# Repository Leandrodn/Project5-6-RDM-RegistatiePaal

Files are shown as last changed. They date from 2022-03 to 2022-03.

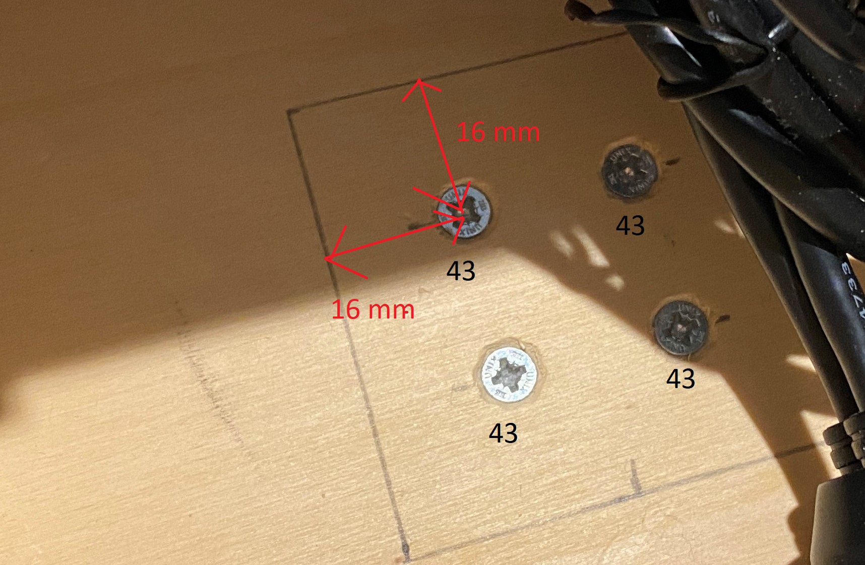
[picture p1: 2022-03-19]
How_To_Build_Your_Own_Registratiesysteem/Detail_Foto's/5291D550-8098-47D3-A0DD-A5EEF2B757EB.jpeg

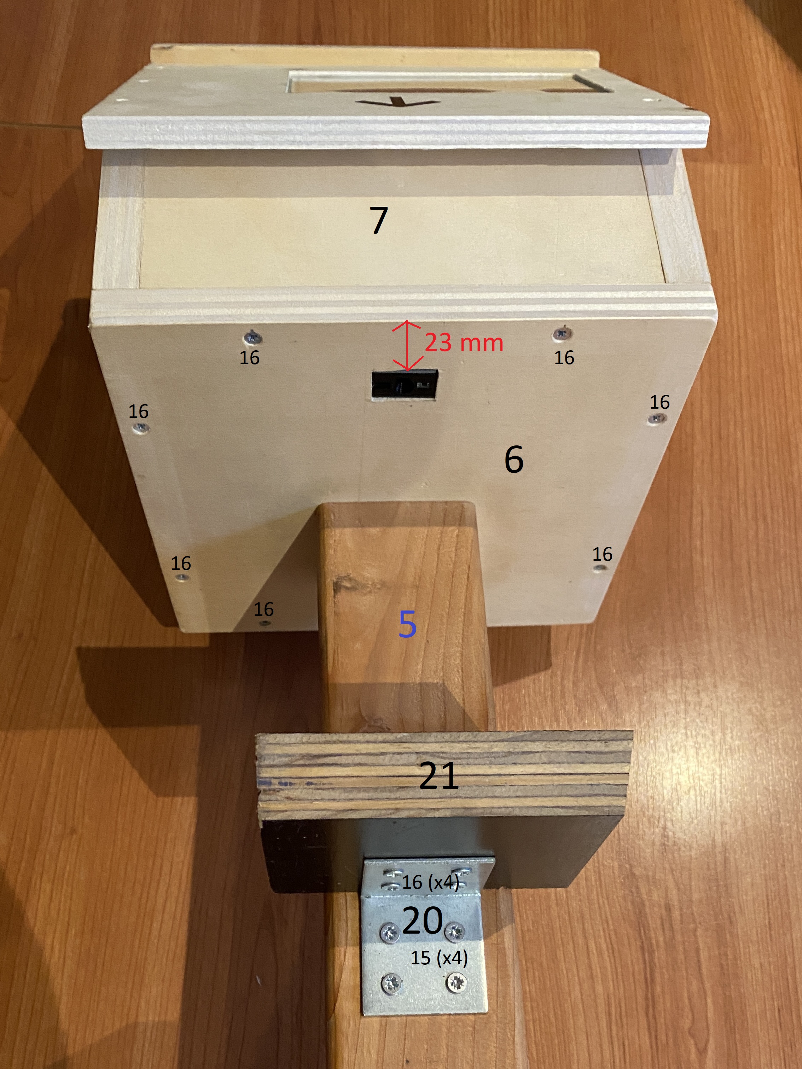
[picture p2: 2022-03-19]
How_To_Build_Your_Own_Registratiesysteem/Detail_Foto's/0E8D077D-FBBA-44C5-A444-DE62F57F8EC1.jpeg

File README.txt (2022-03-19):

Welkom bij de Opleverset van Project 56 - Help de RDM Werkplaatsen beter grip te krijgen op het gebruik van de werkplaatsen

In deze opleverset staan de volgende mappen met de volgende documenten:

- Aantekeningen
Hierin staan 2 tekst bestandjes met aantekeningen van de meeting met de FIT en opmerkingen van de instructeurs op het eerste prototype.

- Datasheets_en_Handleidingen
Hierin staan een aantal handleidingen van bijv. het scherm en scanner en "Pinout's" van de Raspberry Pi's.
	
- Eindmarkt
Hierin staat de powerpoint en bijbehorende video die is gebruikt tijdens de eindmarkt als marketing spotje.
Ook staat hierin de code die is gebruikt waarmee mensen hun studentnummer in konden voeren.
	
- How_To_Build_Your_Own_Registratiesysteem
Hierin staat het pdf document met complete uitleg hoe je het registratiesysteem kan nabouwen.
Ook staat er een mapje in met een aantal detailfoto's en belangrijke maten.
	
- Onderzoek
Hierin staan alle onderzoeken die uitgevoerd zijn voor dit project, zoals de hoofd en deelvragen in het hoofdonderzoek 
en bijv. de beste software voor het registratiesysteem.
Ook staan de belangrijkste onderzoeken erin, namelijk het experimenteel-, gebruikers- en literatuuronderzoek.

- Ontwerpen_en_Schema's
Hierin staan alle ontwerpen en schema's die horen bij dit project.
Onder andere het 3D-ontwerp staat erin met de afmetingen. Ook staan het elektrisch schema, flowchart, DFD, etc erin.

- Software
Hierin staat alle software die gemaakt is voor het registratiesysteem.
De python code van de registratiepaal, de database, de API en het Power BI bestand staan erin.

- Testrapport
Hierin staat het testrapport van alle relevante testen voor het registratiesysteem.

- Trello
Hierin staat een screenshot naar de Trello.
Ook staat er bij de overige documenten (in de 'root' van de opleverset) een tekst bestand met de link naar de trello.

- Userstories
Hierin staat het excel en pdf bestand van alle userstories die gemaakt zijn voor dit project.

- Reflectieverslagen
Hierin staan de reflectieverslagen van alle projectleden.

- Overige documenten
In de 'root' van de opleverset staan alle andere belangrijke en benodigde documenten zoals:
Het beveilgingsplan, de risicoanalyse, de projectdoel koppeling en de requirementsanalyse

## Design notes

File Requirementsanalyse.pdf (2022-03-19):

# Requirements Analyse – Project 56

Help de RDM-werkplaatsen om beter grip te krijgen op het gebruik van de werkplaatsen!

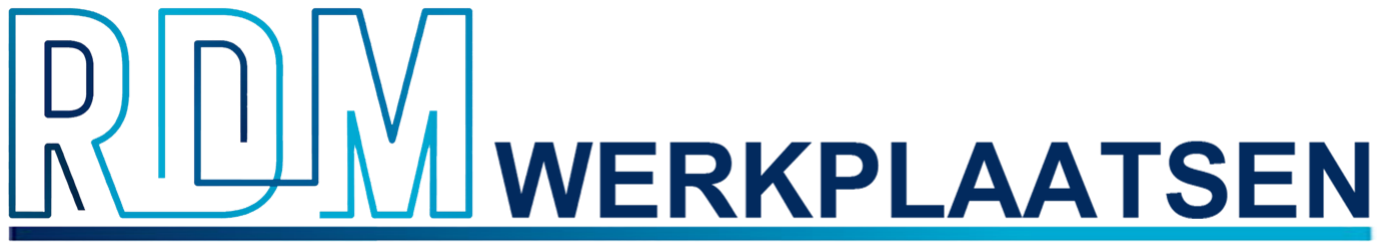
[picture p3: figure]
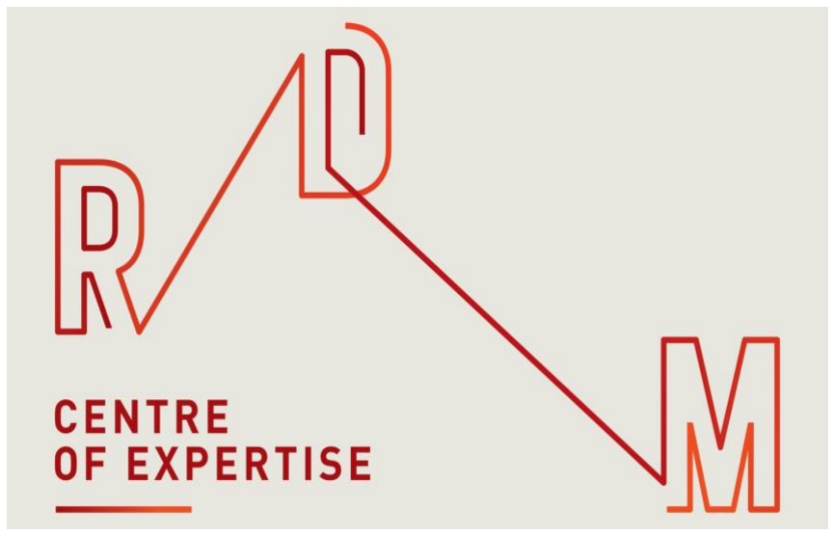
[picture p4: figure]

Projectleden:
- Matthijs Briel (0988991)
- Leandro de Nijs (1003440)
- Tom van Pelt (1003212)
- Gijs Kortlever (1003152)
Inleverdatum: 6 Februari 2022
Begeleiders: Erwin de Mos & S.M. Hekkelman Bedrijfsbegeleider (Product Owner): F.W.J. Joosten Gladon Gelegenheid: Eerste Kans

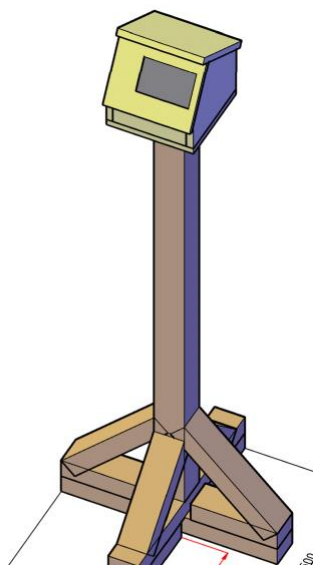
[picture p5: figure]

# Inhoudsopgave

# Inleiding

Deze analyse is geschreven voor Project 56: ‘Help de RDM-werkplaatsen om beter grip te krijgen op het gebruik van de werkplaatsen!’ van jaar 2 van TI. Bij dit project moet er een geautomatiseerd systeem ontworpen en (eventueel) gebouwd worden voor het registeren van bezoeken aan de werkplaatsen op de RDM door studenten. Nu gebeurt dat nog handmatig doordat ze ingetypt worden in Excel. Deze gegevens moeten opgeslagen worden en (makkelijk) uitgelezen kunnen worden voor nadere analyse.

Een ontwerp is bijvoorbeeld een systeem met kastjes bij de ingang van de werkplaatsen waar de student met zijn/haar HR-pas incheckt (en uitcheckt). Deze incheck wordt dan opgeslagen in een database die later weer uitgelezen kan worden.

## Ontwerpen

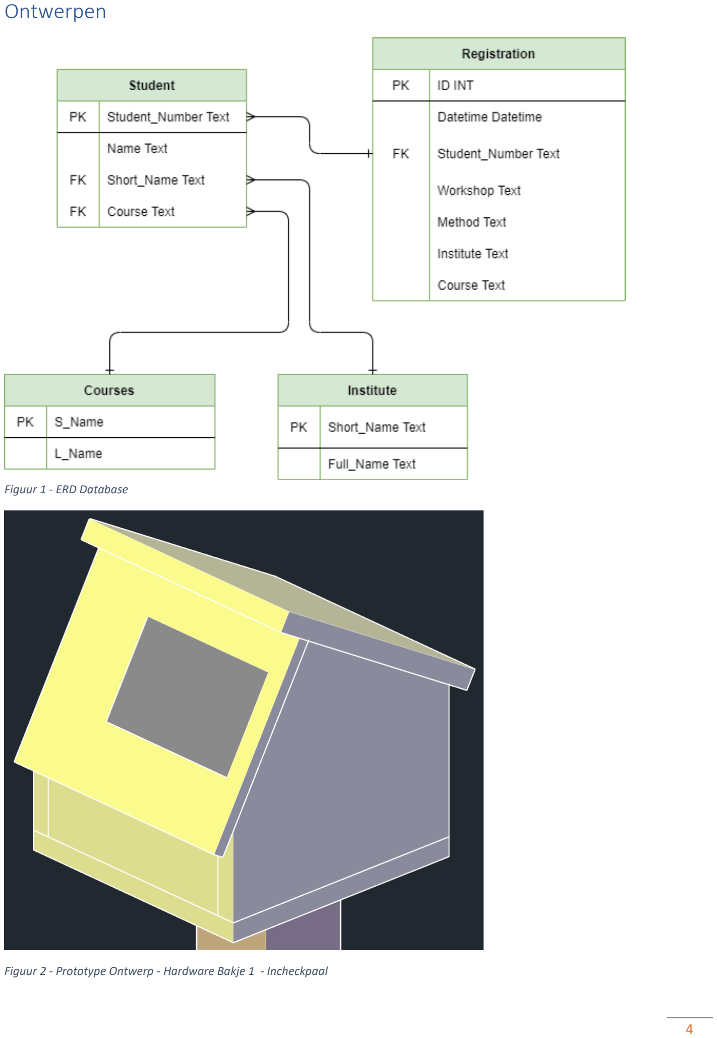
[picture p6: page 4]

Figuur 1 - ERD Database

Figuur 2 - Prototype Ontwerp - Hardware Bakje 1 - Incheckpaal

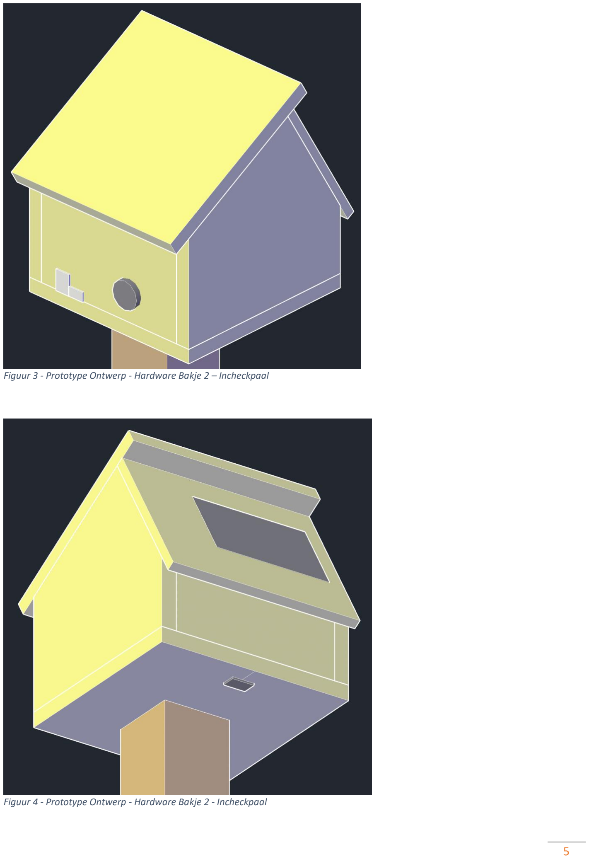
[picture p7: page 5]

Figuur 3 - Prototype Ontwerp - Hardware Bakje 2 – Incheckpaal

Figuur 4 - Prototype Ontwerp - Hardware Bakje 2 - Incheckpaal

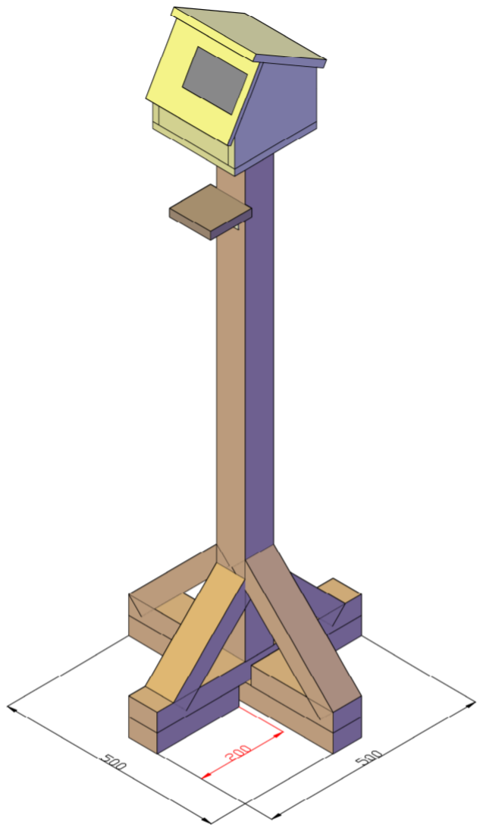
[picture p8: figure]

Figuur 5 - Prototype Ontwerp - Incheckpaal

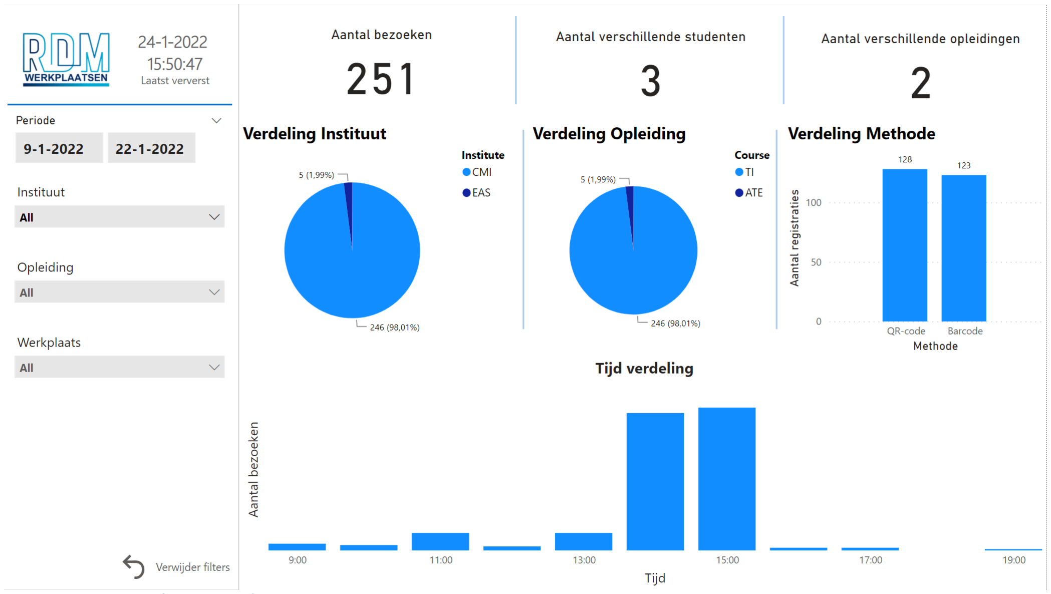
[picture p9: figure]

Figuur 6 – Power BI report – filters links – grafieken rechts

# Product Backlog: Allesbehalve Power BI

Nr. | Functionaliteiten | MoSCoW | Benodigdheden | Geschatte moeilijkheid (1-5)* | Acceptance Criteria
1 Barcode uitlezen met de Raspberry Pi en | 2D-scanner | M 2D barcode scanner | Raspberry Pi | 4 - Een schoolpas kan worden | uitgezelen met de 2D scanner
2 QR-code uitlezen met de Raspberry Pi | en 2D-scanner | M 2D barcode scanner | Raspberry Pi | 4 - Een QR-code kan worden | uitgezelen met de 2D scanner
3 Gegevens van een registratie worden | opgeslagen in een database. | M Database tabel met | student gegeven Database tabel met registraties API | 3 -Data van gescande pas | wordt uitgelezen, gecontroleerd en doorgestuurd.
4 Registraties kunnen worden opgevraagd | via een API | M Database | API | 4 -De registraties kunnen | worden opgehaald uit een database via de api.
5 | Beveiligingsplan | M | Concept-ontwerp om de beveiliging op te baseren. | 3 -Het plan houdt rekening met | zoveel mogelijk zwakheden.
6 | Privacy plan | M | Info over regels waaraan we ons moeten houden. | 3 -Het plan is in | overeenstemming met Nederlandse wetgeving.
7 | Risico log | M | Alle risico’s die zich tijdens en na het project kunnen voordoen | 2 -Alle risico’s zijn in kaart | gebracht met de impact die ze mogelijk hebben en hoe op te lossen.
8 Raspberry Pi maakt verbinding met het | internet | M Raspberry Pi maakt | verbinding met WiFi of Internetkabel | 2 -Raspberry Pi maakt | succesvol connectie met internet via wifi of kabel.

9 Er is duidelijk onderzoek gedaan om de | gemaakte keuzes te onderbouwen | M Onderzoeksverslagen / | Literatuuronderzoek / Gebruikersonderzoek / Experimenteel onderzoek | 3 -Onderzoek stelt duidelijke | vragen met antwoord en geeft adviserende conclusies.
10 Er zijn aanbevelingen gemaakt voor de | Hogeschool Rotterdam als zij zelf de paal willen implementeren | M Aanbevelingen | document | 3 -In het document staan de | aanbevelingen/aanpassingen die Hogeschool moet maken aan de registratiepaal
11 Op de registratiepaal wordt duidelijk | gemaakt dat de incheck is geslaagd op een scherm. | S Een scherm met GUI | Raspberry Pi | 4 -Op het scherm wordt met | een vinkje (of kruis) aangegeven of een scan is geslaagd of niet.
12 Op de registratiepaal wordt duidelijk | gemaakt dat de incheck is geslaagd met een buzzer. | S Een buzzer | Raspberry Pi | 2 -In de registratiepaal zit een | buzzer die een toon aangeeft of een registratie is geslaagd of niet.
13 Op het scherm worden de mogelijke | errors aangegeven. | S GUI | Scherm Raspberry Pi | 2 -Alle errors worden correct | opgevangen en weergegeven op het scherm van de registratiepaal.
14 En plankje om de hoogte voor registreren | aan te geven | W Registratiepaal | Plankje hout | 1 -Het plankje geeft de | correcte hoogte aan voor registreren.
15 Aan de registratiepaal zit een | stekkerdoos voor gemakkelijke toegang tot stroom en aansluiten op het stroomnet van de RDM | W Registratiepaal | Stekkerdoos | 1 -Stekkerdoos aan | registratiepaal is correct geïmplementeerd.

* 1 = zeer makkelijk / 5 = zeer moeilijk

# Product Backlog: Power Bi

Nr. | Functionaliteiten | MoSCoW | Benodigdheden | Geschatte moeilijkheid (1-5)* | Acceptance Criteria
1 | Data kan online worden weergegeven. | M | Power BI | 5 | -Data uit de database kan worden ingelezen via Power BI.
2 Power BI report is beveiligd achter een inlog scherm van | de Hogeschool. | M | Power BI | 1 | -In Power BI worden mensen toegevoegd die deel kunnen nemen aan het report. Inloggen gebeurt via HR-account
3 | Registraties worden uit de database gehaald via de API. | M | API, database, Power BI | 4 -registraties worden | opgehaald uit database via API
4 | Registraties kunnen worden gedownload naar Excel. | M | API, database, Power BI | 3 -de registratiedata | kan worden gedownload
5 De verdeling tussen de instituten wordt in een Pie chart | weergegeven | M API, database, | Power BI | 3 -Instituut data wordt | opgehaald en weergeven in een Pie chart.
6 De verdeling tussen de opleiding wordt in een Pie chart | weergegeven | M API, database, | Power BI | 3 -opleiding data | wordt opgehaald en weergeven in een Pie chart.

7 | Het aantal bezoeken wordt weergeven | M | API, database, Power BI | 3 -er wordt geteld | hoeveel bezoeken er zijn. Hier wordt ook aangeven het aantal studenten wat een werkplaats heeft bezocht.
8 | Er is in het report een globale filter van de werkplaatsen | M | Power BI | 2 | -er is een globale filter aan de linkerkant die filtert op werkplaats. Door de filter worden de grafieken veranderd
9 | Er is in het report een globale filter van de opleiding | M | Power BI | 2 | -er is een globale filter aan de linkerkant die filtert op opleiding. Door de filter worden de grafieken veranderd
10 | Er is in het report een globale filter van het instituut | M | Power BI | 2 | -er is een globale filter aan de linkerkant die filtert op instituut. Door de filter worden de grafieken veranderd

11 | Er is in het report een globale filter van de datum | M | Power BI | 2 | -er is een globale filter aan de linkerkant die filtert op datum. Hier kan een periode worden geselecteerd Door de filter worden de grafieken veranderd
12 | Registraties worden weergegeven in een tabel | S | API, database | 4 | -registratiedata wordt in een tabel weergegeven op de webapplicatie
13 | De data wordt minimaal een keer per dag ververst | S | Power BI | 1 | -het report is ingesteld dat het een keer per dag wordt ververst.
14 Er is een grafiek die het de QR-code / barcode | registraties bijhoud. | W API, database, | Power BI | 3 -de grafiek toont de | verdeling tussen QR-code en Barcode
15 Er is een grafiek die de tijdsverdeling van de | werkplaatsen bijhoudt. | W API, database, | Power BI | 3 -de grafiek toont de | tijdsverdeling aan. Hoe drukker hoe hoger de bar
16 Er wordt bijgehouden wanneer de data voor het laatst is | ververst. | W Power BI, custom | query | 3 -linksboven wordt | aangeven wanneer de data voor het laatst is ververst.

* 1 = zeer makkelijk / 5 = zeer moeilijk

# Specificatie

Nr. | Requirements | MoSCoW | Oorsprong | Acceptance Criteria | Test
1 Er kan een studentnummer van een QR-code | uit de HR-app worden uitgelezen met een QR-code scanner. | M | PO | Het studentnummer uit de QR-code uit de HR-app kan worden uitgelezen door deze code onder de QR-code scanner te houden. (zie 2 -backlog) | Als de QR-code uit de HR-app onder de QR-code scanner wordt gehouden, leest deze scanner hem uit en geeft de scanner een licht- en geluidssignaal dat de QR-code is uitgelezen.
2 Er kan een studentnummer van de barcode | op de HR-pas worden uitgelezen met een barcode scanner. | M | PO | De barcode wordt met succes uitgelezen van de HR-pas door de HR-pas voor de barcode scanner te houden. (zie 1 - backlog) | Als de barcode van de HR-pas onder de barcode scanner wordt gehouden, leest deze scanner hem uit en geeft de scanner een licht- en geluidssignaal dat de barcode is uitgelezen.
3 Er is een database in SQLite gemaakt waarin | de data staan die in de ERD staat, zie figuur 1. | M | Projectleden | De database is opgesteld volgens de ERD. (zie figuur 1) | Alle benodigde informatie die we nodig hebben, zit in de database.

4 Er is een RestAPI in python gemaakt die de | hardware met de database verbindt. | M Projectleden | / Expert | De API maakt correct verbinding voor het uitvoeren van POST/GET request. (zie 3 - backlog) | Code gemaakt die de data van de scanner naar de database kan sturen en ophalen. Ook zal de API worden ge-unit test zodat deze geen fouten bevat.
5 Er is een Power BI report gemaakt die data | ophaalt. | M Projectleden | / PO | De Power BI is gemaakt in overeenstemming met de PO. Deze haalt data op uit de database via de API. (zie 3 – backlog Power BI) | Power BI is voorgelegd aan de PO en voldoet aan haar wensen.
6 Power BI laat grafisch de registratie data uit | de database zien door middel van grafieken en diagrammen. | M | PO | In Power BI wordt de registratiedata correct uitgelezen en grafisch weergegeven. (zie 5/6/14/15 – backlog Power BI) | Power BI is voorgelegd aan de PO en voldoet aan haar wensen.

### 7 In Power BI kunnen ~4 mensen inloggen met

hun eigen inloggegevens.

M | PO | In Power BI zijn mensen toegevoegd die kunnen inloggen. Deze mensen kunnen ieder het report inzien door in te loggen met hun Hogeschool account. (zie 2 – backlog Power BI)
De toegevoegde
accounts kunnen
worden gebruikt om in
te loggen. Om dit te
testen zal de Power BI
worden geopend in een
incognito tabblad zodat
een persoon niet per
ongeluk al ingelogd
was.

### 8 De registratie data is te exporteren naar een

Excel bestand via Power BI.

M | PO | De tabel met alle registraties van de werkplaatsen is te downloaden naar een voor Excel compatibel bestand. (zie 4 – backlog Power BI)
Door op de knop te
drukken in Power BI zal
de data uit de database
worden geconverteerd
naar een bestand die
compatibel is met Excel
en vervolgens
gedownload naar de
computer waarop de
knop is ingedrukt.

### 9 Er is een ontwerp voor een incheckpaal met

een stevige voet van 50 x 50 cm, een paal met hoogte van ongeveer 110 cm en een ‘huisje’ bovenop de paal (volgens de afmetingen van 3D-ontwerpen) waarin een 2D code scanner, Raspberry Pi 3b (of hoger), 5 inch LCD scherm en kabels moeten passen. Ook moeten er uitsparingen zijn waarin de 2D code scanner past en uitsparingen voor het scherm aan de voorkant van het ‘huisje’. Daarnaast zitten er connectoren aan de achterkant zodat er stroom en eventueel een internetkabel kan worden aangesloten.

M | PO | Het ontwerp voldoet aan de gestelde eisen.
Het ontwerp bevat de
afmetingen die worden
gecontroleerd of die
binnen de waardes
vallen, ook zal de
hardware worden
geplaatst om te kijken of
er daadwerkelijk
voldoende ruimte is in
het bakje. De scanner
moet naar beneden
gericht staan en een
bar- en QR-code
kunnen scannen. Ook
moet de Raspberry Pi
aangesloten kunnen
worden als het bakje
dichtgeschroefd zit.

### 10 Er is duidelijk gemaakt via een scherm en/of

buzzer dat de bar- / QR-code goed is gescand en de registratie dus is geslaagd.

M PO /
Projectleden
/
Feedbackgr
oep

In het prototype wordt
duidelijk gemaakt dat een
registratie is geslaagd via de gestelde requirements. (zie 11/12 - backlog)

De methode voor het
duidelijk maken van een
geslaagde registratie
wordt getest door hier
code voor te schrijven
om een registratie te
simuleren. De barcode
op de HR-pas en de
QR-code in de HR-app
moet gescand kunnen
worden. Als een van de
codes gescand is moet
dit duidelijk gemaakt
worden door een
scherm, luide toon en/of
LED, zodat de gebruiker
weet of hij/zij goed
geregistreerd is.
11 Er is een architectuur ontwerp om duidelijk te | maken uit welke onderdelen het registratiesysteem bestaat. | M | PO | Alle losse onderdelen staan in het architectuur ontwerp en er wordt duidelijk met welk onderdeel deze is verbonden. | Architectuurontwerp is voorgelegd aan de feedback groep en is goedgekeurd.
12 Alle belangrijke risico’s zoals stroom uitval of | ziekte van een projectlid zijn in kaart gebracht in een risicolog. | M | Projectleden | Alle belangrijke risico’s zijn in kaart gebracht, de mogelijke gevolgen hiervan en hoe de risico’s voorkomen en/of verholpen kunnen worden. (zie 7 - backlog) | Risico’s zijn voorgelegd en besproken met PO. De PO keurt de risico’s goed of af.

13 In Power BI zijn globale filters die de data | filteren en weergeven | M | PO | De filters geven het verwachte resultaat in de grafieken. (zie 8/9/10/11 – backlog Power BI) | Filter op een aantal zaken en controller of dit is wat er wordt verwacht.
14 In de Power BI zijn de registraties zichtbaar | met bijbehorende data. | S Instructeurs | / PO | De verschillende registraties met datum zijn zichtbaar in een tabel in de webapplicatie. | Het resultaat wordt voorgelegd aan de PO.

# Changelog

Versie | Datum | Aanpassing | Auteur
1.0 | 15/10/2021 | Eerste versie | Matthijs Briel
1.1 | 15/10/2021 | Aanvulling | Matthijs Briel
1.2 | 17/11/2021 | Aanvulling Specificatie | Leandro de Nijs
1.3 | 17/11/2021 | Aanvulling backlog | Leandro de Nijs
1.4 | 20/11/2021 | Kleine lay-out aanpassing | Tom van Pelt
1.5 | 21/11/2021 | Ontwerpen toegevoegd / aanvulling specificatie | Tom van Pelt
1.6 | 21/11/2021 | Aanvulling | Leandro de Nijs
1.7 | 15/01/2022 | Wijziging van ontwerp foto’s registratie paal en afbeeldingen op Voorblad toegevoegd | Tom van Pelt
1.8 | 24/01/2022 | Grote aanpassing | Leandro de Nijs & Gijs Kortlever
1.9 | 31/01/2022 | Aangepaste ERD toegevoegd | Tom van Pelt

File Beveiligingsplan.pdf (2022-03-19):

# Beveiligingsplan – Project 56

Help de RDM-werkplaatsen om beter grip te krijgen op het gebruik van de werkplaatsen!


Projectleden:
- Matthijs Briel (0988991)
- Leandro de Nijs (1003440)
- Tom van Pelt (1003212)
- Gijs Kortlever (1003152)
Inleverdatum: 6 Februari 2022
Begeleiders: Erwin de Mos & S.M. Hekkelman Bedrijfsbegeleider (Product Owner): F.W.J. Joosten Gladon Gelegenheid: Eerste Kans


## Inhoudsopgave

## Hoofdstuk 1

### Data Flow Diagram (DFD)

- Zie Bijlage 1.

### Risicoanalyse algemeen / project specifiek

- In deze risicoanalyse wordt omschreven welke aanvallen (risico’s) er mogelijk zijn en hoe deze uitgevoerd kunnen worden.

Algemeen
Nr. | Risico | Impact (1-5)* | Kans (1-5)* | Hoe te voorkomen en hoe op te lossen.
1 | Componenten gaan kapot. | 4 | 2 | Kijken of er nog componenten zijn ter vervanging. Zo niet, dan de componenten bestellen. Komen de componenten niet binnen de huidige sprint aan, dan moet het door worden geschoven naar volgende sprint.
2 Componenten die besteld zijn komen | niet op tijd aan. | 3 | 2 | Kijken of de sprint nog voltooid kan worden. Zo niet, dan moet het door worden geschoven naar volgende sprint planning.
3 | Geen internetverbinding. | 5 | 3 | Er altijd rekening mee houden en dus belangrijke documenten downloaden in plaats van online te bekijken.
4 Tijdens een sprint erachter komen dat | wat er in de sprint backlog staat voor de huidige sprint, niet haalbaar is in de tijd (die nog over is). | 5 | 2 | Kijken welke user story aangepast / eruit gehaald moet worden om de sprint wel haalbaar te maken.
5 | Een projectlid wordt ziek. | 3 | 2 | Kijken wanneer het projectlid ziek is geworden. In het begin en kort ziek? -> dan is zijn deel nog haalbaar om te halen. In het midden/eind en langer ziek? -> Taakdeel verdelen over de andere projectleden.
6 Scholen gaan weer dicht i.v.m. nieuwe | coronamaatregelen. | 5 | 1 | Kijken wat er thuis gedaan kan worden en kijken of er bij iemand (veilig) afgesproken kan worden om aan het project te werken.
7 | Een projectlid stopt met de opleiding. | 5 | 1 | Taken van huidige sprint van stoppende projectlid verdelen over de rest van de projectleden. De andere projectleden moeten rekening houden met meer werk voor de rest van het project.

Project specifiek
Nr. | Risico | Impact (1-5)* | Kans (1-5)* | Hoe te voorkomen en hoe op te lossen.
1 | Opdrachtgever is niet bereikbaar. | 2 | 4 | Vooraf informeren wanneer de opdrachtgever bereikbaar is en dus optimaal gebruik maken van de contact-momenten.
2 | Budget raakt op. | 5 | 2 | Voorzichtig omgaan met de aankoop van componenten. En goed bijhouden wat en voor welke prijs we spullen hebben gekocht.
3 | Stroom valt uit op de RDM | 5 | 1 | Hier kunnen wij niet zo veel aan doen, dit moet worden opgelost door de werknemers bij de RDM. Wel kunnen we een tijdelijke oplossing bedenken.
4 | Internet valt weg op de RDM | 4 | 3 | Hier kunnen wij niet zo veel aan doen, dit moet worden opgelost door de werknemers bij de RDM. Wel kunnen we een tijdelijke oplossing bedenken.

* 1-5 = 1 is minst belangrijk, 5 is meest belangrijk

Legenda:
- Impact 1 = erg klein, heel erg makkelijk op te vangen als dit voorkomt
- Impact 5 = erg groot, moeten grote maatregelen worden genomen om dit probleem op te lossen
- Kans 1 = erg klein, komt eigenlijk niet voor, maar zou in theorie voor kunnen komen
- Kans 5 = erg groot, zeer aannemelijk dat dit voor kan komen tijdens een van de sprints

### Attack Tree

- Zie Bijlage 2

## Hoofdstuk 2

### Beveiligingsrisico’s

In onderstaande tabel staan de meest belangrijke en voorkomende beveiligingsrisico’s.

Risico Nr. | Risico | Uitvoering Risico
1 | Met requests naar de server is er toegang mogelijk naar de database. | Door URL’s die niet gebruikt worden door de API te gebruiken kunnen er requests naar de serve gestuurd worden die niet gecheckt worden door de API.
2 | Iemand kan bij de data in de database komen zonder de API te gebruiken. | Als er toegang is tot de bestanden hiërarchie van de server zou het bestand van database geopend kunnen worden.
3 | Iemand kan zomaar de registratiepaal openmaken en bij de binnenkant komen. | Iemand kan bij de binnenkant komen door een plankje weg te trekken doordat deze niet goed vastzit. Ook kan er bijvoorbeeld nog een gat zitten in de behuizing waardoor er zeer gemakkelijk bij gekomen kan worden.
4 | Iemand kan computer van de registratiepaal bedienen. | Iemand sluit een toetsenbord of muis aan via een usb-poort aan de binnenkant of buitenkant van de behuizing en kan zo de computer van de paal besturen en bijv. de registratie software (GUI) uitzetten of malware laten draaien.
5 | Iemand kan een bar/QR-code scannen die malware bevat | Iemand scant een QR-code met bijv. een commando waarmee er data kan worden gestuurd naar de database die de database kan hacken.
6 | Als iemand de juiste URL heeft van de API, kan deze zonder authenticatie de data inzien/versturen. | De URL is bekend bij iemand die hier eigenlijk niet tot geautoriseerd hoort te zijn. Deze persoon kan via deze URL de JSON-data uit de API ophalen en zelf weergeven.

### Maatregelen

In onderstaande tabel staan de maatregelen die genomen moeten worden om de beveiligingsrisico’s zoveel mogelijk te verhelpen.

Risico Nr. | Maatregel Nr. | Maatregel
1 | 1 | Specifieke URL’s in de database die over bepaalde delen van de database gaan. Alle requests naar de server die niet gelijk zijn aan een van deze URL’s worden genegeerd. Alleen POST en GET requests worden geaccepteerd. Vervolgens moet de URL ook kloppen met wat vastgelegd staat in de documentatie.
2 | 2 | In de API wordt alleen data die gelijk is aan afgesproken formats herkend, alles dat niet volgens de documentatie correct is wordt genegeerd en weggegooid. Denk hierbij aan extra ongewenste data toevoegen achter een legitiem data format. Deze data worden genegeerd doordat alleen de data met het juiste voorvoegsel wordt gepakt en deze data ook nog wordt gecheckt of het bijvoorbeeld de juiste string lengte of zelfs juiste inhoud bevat. Dit alles om te zorgen zodat alleen gewenste data überhaupt dicht bij de database kan komen.
3 | 3 | Het materiaal waarmee de registratiepaal wordt gemaakt is stevig en zit goed vastgeschroefd zodat er tenminste gereedschap aan toe moet komen om de registratiepaal open te maken. Eventueel kan het hout en de schroeven ook nog verlijmd worden zodat de registratiepaal niet meer uit elkaar te halen is. Als er gelijmd wordt is het aan te raden, om ergens een klepje te maken met een goed scharnier en slot erop zodat er toch nog bij de binnenkant gekomen kan worden, maar alleen door degenen die daartoe bevoegd zijn.
4 | 4 | Er moeten geen USB-poorten zijn gemaakt aan de buitenkant zodat er bijvoorbeeld geen toetsenbord of muis kan worden aangesloten. Voor het prototype wat er bij dit project wordt opgeleverd is dit wel zo, omdat het heel handig is met testen. Ook moet de touchscreen uitstaan op het scherm. Dit is makkelijk door gewoon geen software te installeren op de Pi die ervoor zorgt dat de touchscreen werkt. Default werkt de touchscreen al niet namelijk.
5 | 5 | In de software (GUI) van de registratiepaal moet worden gecheckt met bijvoorbeeld een if statement of de data die gescand wordt 7 tekens lang is en alleen uit cijfers bestaat. Dat is namelijk het format van een studentnummer. Daardoor kan er geen andere data dan alleen een studentnummer worden gestuurd naar de API.
6 | 6 | Zelf geen maatregelen voor genomen, wel een aanbeveling.

## Bijlagen

### Bijlage 1 – Data Flow Diagram

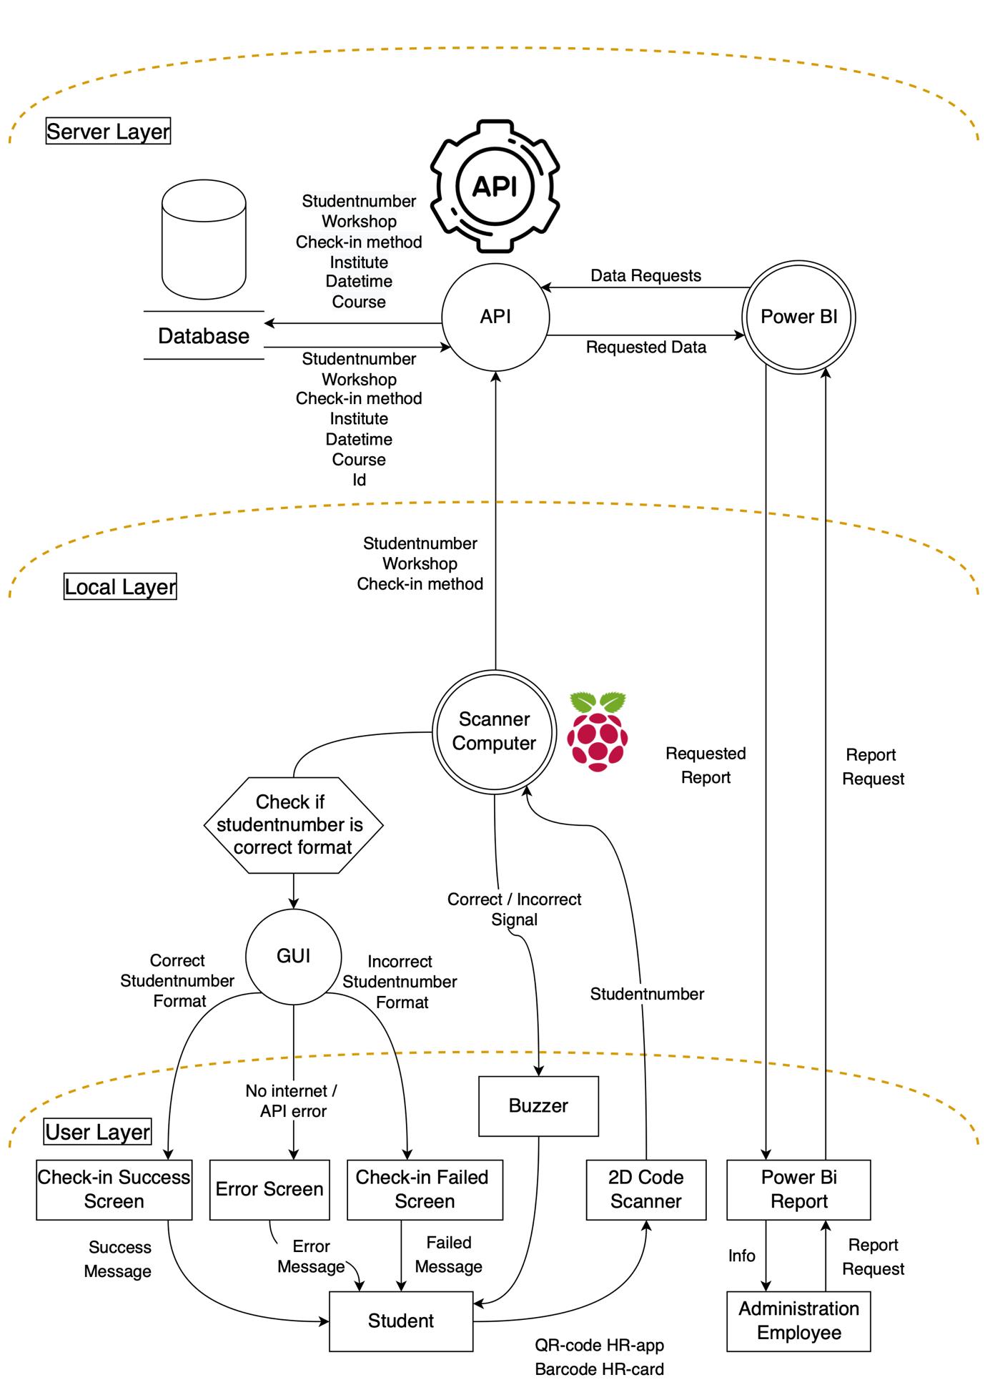
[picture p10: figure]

### Bijlage 2- Attack Tree

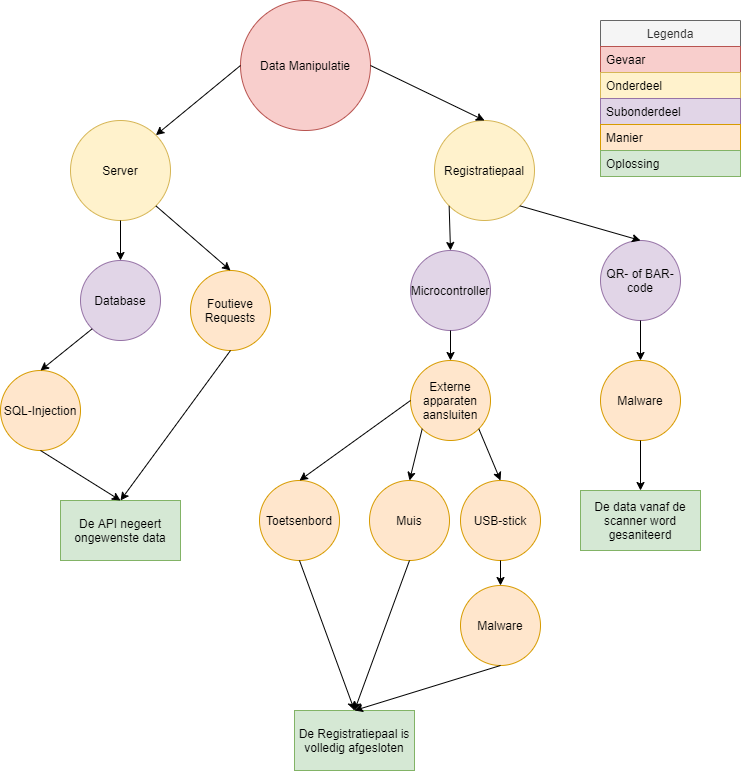
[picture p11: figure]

## Changelog

Versie Datum | Aanpassing | Auteur
1.0 | 15/12/2021 | Eerste versie | Matthijs Briel
1.1 | 19/12/2021 | Bijlage toegevoegd en kleine lay-out aanpassing | Tom van Pelt
1.2 | 15/01/2022 | Afbeeldingen op Voorblad toegevoegd | Tom van Pelt
1.3 | 24/01/2022 | Grote aanpassingen | Gijs Kortlever
1.4 | 26/01/2022 | DFD aangepast naar nieuwe versie | Tom van Pelt
1.5 | 30/01/2022 | Aanpassingen en grote aanvullingen | Tom van Pelt
1.6 | 31/01/2022 | Aanvulling / aanpassingen | Leandro de Nijs & Tom van Pelt & Gijs Kortlever

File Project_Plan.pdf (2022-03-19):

# Project Plan – Project 56

Help de RDM-werkplaatsen om beter grip te krijgen op het gebruik van de werkplaatsen!

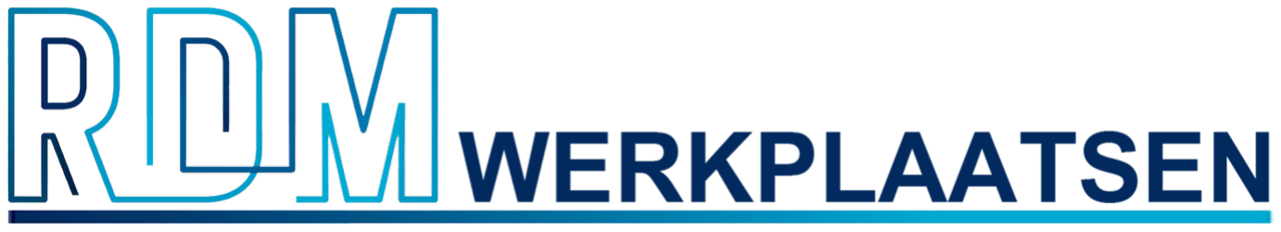
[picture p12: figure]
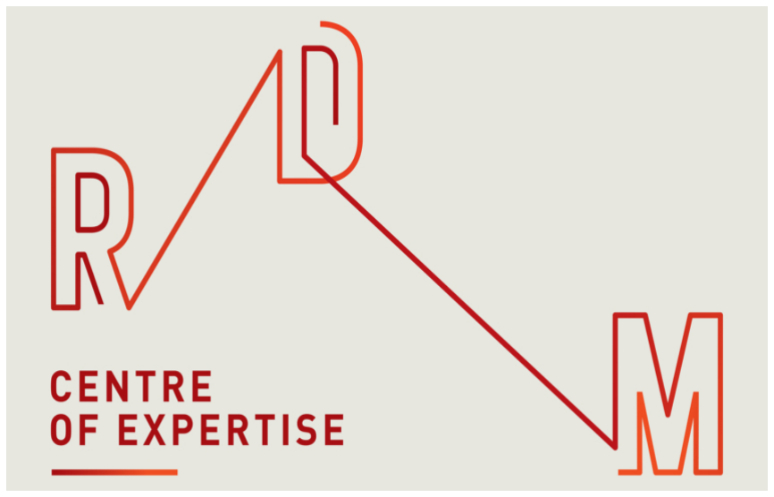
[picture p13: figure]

Projectleden:
- Matthijs Briel (0988991)
- Leandro de Nijs (1003440)
- Tom van Pelt (1003212)
- Gijs Kortlever (1003152)
Inleverdatum: 6 Februari 2022
Begeleiders: Erwin de Mos & S.M. Hekkelman Bedrijfsbegeleider (Product Owner): F.W.J. Joosten Gladon Gelegenheid: Eerste Kans

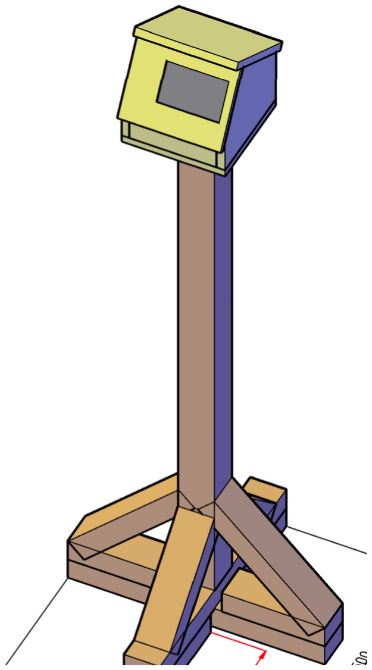
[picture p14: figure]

# Inhoudsopgave

# Wat is een Project Plan?

- Een projectplan is een document of canvas dat beschrijft hoe, wanneer en door wie een specifiek target of een verzameling van targets moet worden bereikt. Dit target of deze verzameling bevat projectproducten, termijnen, kosten, kwaliteitseisen en benefits. Zo’n plan kan heel wat tekst bevatten om uit te leggen wat er zal gebeuren.

# Waar is een Project Plan onderdeel van?

- Een projectplan is een onderdeel van de projectmethodiek Prince 2. Deze methode gaan we bij ons project niet gebruiken. Bij ons project maken we namelijk gebruikt van de projectmethodiek SCRUM. We maken echter wel een projectplan, omdat onze Product Owner daar om heeft gevraagd.

# Wat moet er staan in een Project Plan?

- In een projectplan staan de volgende dingen:
- Naam van het project
- Opdrachtgever / Opdrachtgeefster
- Randvoorwaarden (zaken die kader stellend zijn en harde voorwaarden zijn voor inhoud of uitvoering)
- Kwaliteit (afgesproken eisen waaraan het projectresultaat moet voldoen)
- Aanpak (benadering van het project in grote lijnen)
- Belanghebbenden (partijen die positieve of negatieve consequenties van het project ondervinden)
- Risico’s (mogelijke gebeurtenissen die een negatieve invloed hebben op de projectuitvoering.
- Projectteam (projectleider en projectleden)
- Tijd (Eis of wens over de eindtijd van het project)
- Geld (Wat brengt het op, wat zijn de projectkosten en terugkerende kosten)
- Afhankelijkheden (andere initiatieven of omstandigheden waarmee je rekening moet houden, inhoudelijk of in tijd, geld of organisatie)

# Waar is een Project Plan voor bedoeld?

- Om snel te kunnen zien wat voor project het is, wie er allemaal mee te maken hebben, wat de kosten zijn, etc. Alles wat eigenlijk met een project te maken heeft kan makkelijk gevonden worden waardoor er een duidelijk overzicht is.

# Bronnen

Janse, B. (2021, 6 mei). Wat is de prince2 project management methode? Uitleg & fasen | toolshero.
Toolshero. Geraadpleegd op 4 oktober 2021, van https://www.toolshero.nl/project-management/prince2-methode/

PRINCE2. (2021, 14 augustus). In Wikipedia. https://nl.wikipedia.org/wiki/PRINCE2

# Bijlagen

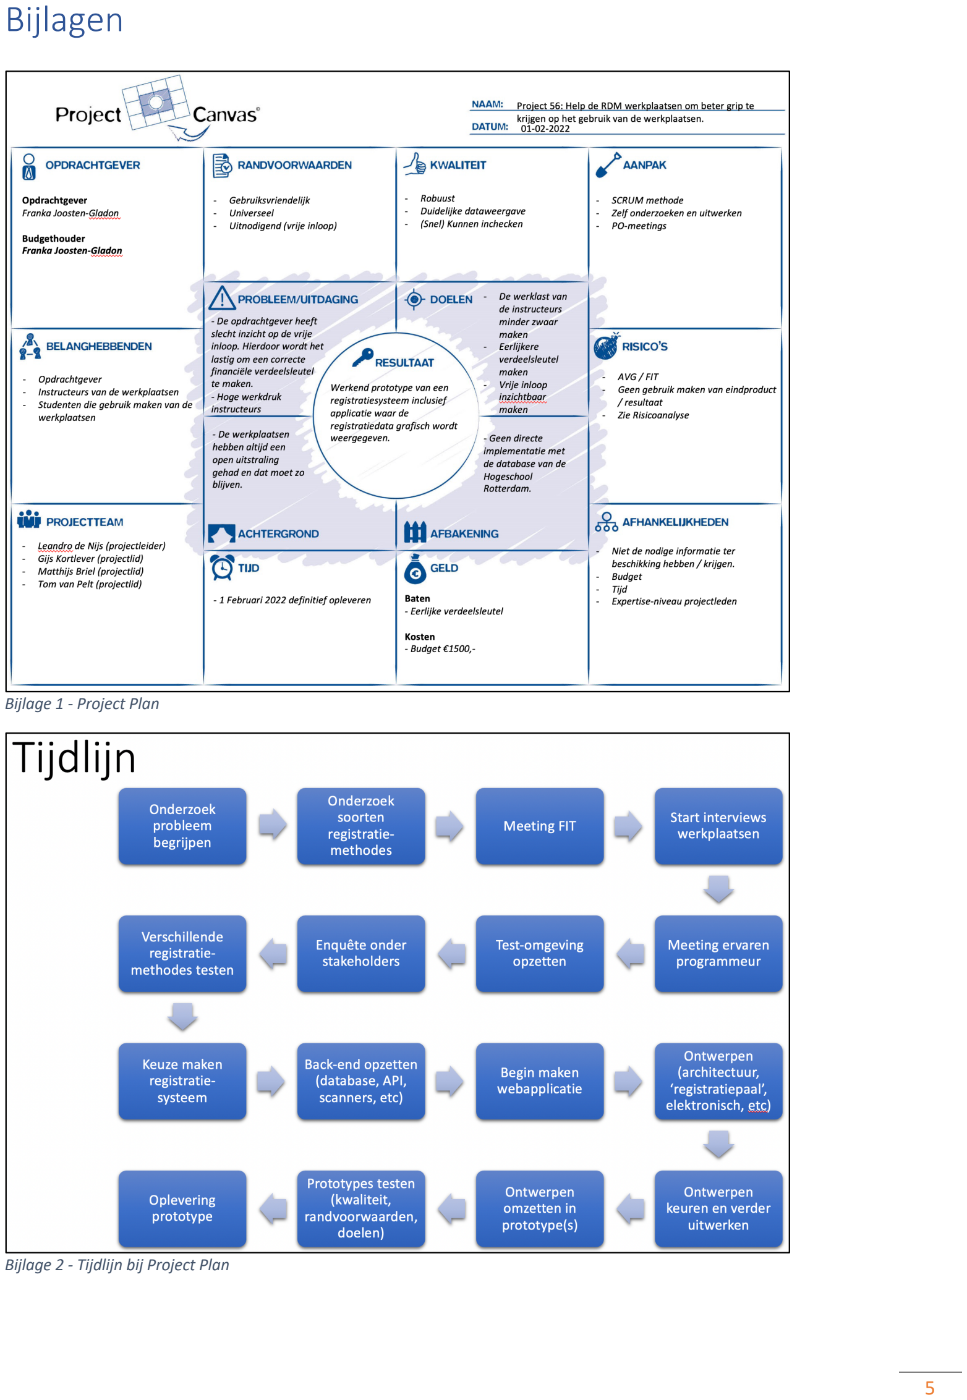
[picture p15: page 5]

Bijlage 1 - Project Plan

Bijlage 2 - Tijdlijn bij Project Plan

# Changelog

Versie | Datum | Aanpassing | Auteur
1.0 | 27/09/2021 | Eerste versie | Tom van Pelt
1.1 | 04/10/2021 | Deelvragen beantwoord | Tom van Pelt
1.2 | 19/11/2021 | Kleine lay-out aanpassingen | Tom van Pelt
1.3 | 15/01/2022 | Afbeeldingen op Voorblad toegevoegd | Tom van Pelt
1.4 | 20/01/2022 | Bijlagen toegevoegd | Tom van Pelt

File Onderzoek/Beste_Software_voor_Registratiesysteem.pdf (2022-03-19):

# Onderzoek: Software – Project 56

Help de RDM-werkplaatsen om beter grip te krijgen op het gebruik van de werkplaatsen!


Projectleden:
- Matthijs Briel (0988991)
- Leandro de Nijs (1003440)
- Tom van Pelt (1003212)
- Gijs Kortlever (1003152)
Inleverdatum: 6 Februari 2022
Begeleiders: Erwin de Mos & S.M. Hekkelman Bedrijfsbegeleider (Product Owner): F.W.J. Joosten Gladon Gelegenheid: Eerste Kans


# Inhoudsopgave

# Wat is de beste programmeertaal voor de hardware?

- Python. Deze programmeertaal is erg groot en heeft heel veel mogelijkheden en kan direct draaien op een aantal microcontrollers waardoor deze microcontrollers beter aangestuurd kunnen worden. Omdat deze taal zo groot is, zijn er ook veel externe libraries voor beschikbaar die de connectie tussen de hardware en software makkelijker maken. Tevens is de taal ook aardig efficiënt en is het een erg toegankelijke programmeertaal.
- C++. Deze programmeertaal is ook erg groot en heeft ook veel mogelijkheden. Deze taal kan ook direct draaien op bijvoorbeeld een Raspberry Pi Pico. Ook zijn er veel externe libraries voor beschikbaar. De taal is efficiënter en stabieler dan Python maar wel moeilijker te programmeren.

# Wat is de beste manier om data weer te geven?

Om dit te kunnen bepalen is er eerst gekeken naar een aantal opties. Hieruit zijn twee mogelijke opties ontstaan: een applicatie of een webapplicatie. Ieder van deze twee heeft zijn voor- en nadelen.

### Applicatie

Voordelen: | Nadelen:
Minder veiligheidsrisico’s | Moet geïnstalleerd worden
Sneller dan een website | Internet bereik noodzakelijk
Grotere functionaliteit aangezien ze toegang hebben tot de middelen van de computer waar die opstaat. | Moeilijk bij te houden/updaten
Geen hosting nodig | Alleen toegankelijk op een computer die de applicatie heeft geïnstalleerd
| Systeem gebonden (verschillende versies Windows / Mac)
| Vereist vrije ruimte

### Web applicatie

Voordelen: | Nadelen:
Overal beschikbaar | Minder veilig
Makkelijk te laten zien tijdens een presentatie | Internet bereik noodzakelijk
Makkelijker toegankelijk voor meerdere personen | Hosting nodig

Beter up to date te houden
Niet afhankelijk van systeem vereisten
Veel documentatie over grafische weergave Cross-platform beschikbaar (telefoon, tablet, Mac, etc.)

De eisen waar het data weergave platform in ieder geval aan moet voldoen zijn:
- Connectie met een database/API
- Grafische weergave van de data met grafieken
- Mogelijk maken om data te exporteren naar Excel
- Mogelijkheid voor veiligheid en toegang
- ~4 mensen moeten toegang hebben tot de data
- Overzichtelijk en snel

### Conclusie

Uit het onderzoek blijkt dat het handigste is om gebruik te maken van een webapplicatie. Een webapplicatie is toegankelijker dan een applicatie die geïnstalleerd moet worden, omdat er makkelijk meer mensen op kunnen wat ook een vereiste is. Ook vormt een webapplicatie over het algemeen een betere ervaring voor de gebruikers. Een ander belangrijk punt is dat een webapplicatie cross-platform is. Cross-platform betekent dat het
kan draaien op een telefoon, Windows
Computer, Mac, etc. Dit is erg belangrijk

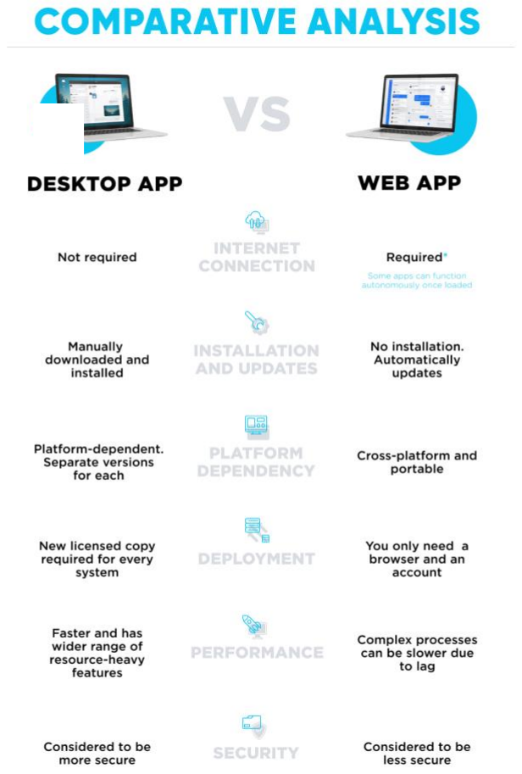
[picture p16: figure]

omdat meerdere mensen op verschillende platformen erop moeten kunnen.

# Hoe kunnen we het beste een webapplicatie maken?

Om bovenstaande vraag te kunnen beantwoorden is er een interview gedaan met een expert op het gebied van programmeren: Jacques de Hooge. Jacques is een ervaringsdeskundige met bijna 50 jaar ervaring op het gebied van programmeren. Er zijn een aantal vragen aan hem gesteld en de samengevatte antwoorden zijn hieronder te lezen.

Allereest het maken van het front-end van een webapplicatie. De beste en makkelijkste manier om een front-end te maken is volgens Jacques door gebruik te maken van React. React is een library voor de programmeertaal Javascript, maar zou net zo goed een taal op zich kunnen zijn. Het is een library om gebruikersinterfaces te maken in Javascript. Er is heel veel documentatie over te vinden en volgens hem is het voor onze doeleinden de beste manier.

Samen met React raadt hij aan om gebruik te maken van Material-UI als template van de gebruikersinterface. Material-UI is een library die de mogelijkheid biedt om fundamentele en geavanceerde componenten snel, robuust en aanpasbaar te maken.

Als derde punt raadde Jacques aan om de server te programmeren in Python gebruikmakend van Flask of Django. Om de connectie te maken tussen de database en de webapplicatie is er een API nodig. “Een API (Application Programming Interface) is een software-interface die het mogelijk maakt dat twee applicaties met elkaar kunnen communiceren.”¹
Jacques heeft ons aanbevolen om gebruik te maken van een RestAPI. “REST (Representational State Transfer) is een stijl van software architecture voor het ontwerp van netwerkapplicaties. Het fundamentele concept van een RESTful API is de 'resource'. Alle informatie die benoemd kan worden is een resource: een document, afbeelding, verzameling (collection) van resources, niet-virtueel object (bijvoorbeeld een persoon) etc. REST gebruikt een resource identifier om een resource te identificeren.”

2

Als laatste raadde Jacques aan om zo veel mogelijk berekeningen ‘client side’ uit te voeren. Door berekeningen client side uit te voeren wordt de server minder belast en blijft de webapplicatie snel mochten er meer mensen tegelijk op de webapplicatie zitten.

1 https://www.salesforce.com/nl/blog/2019/10/wat-is-een-api.html
2 https://www.transip.nl/knowledgebase/artikel/2997-wat-is-een-rest-api/

### Resultaten

Server
De API is gemaakt in Python gebruik makende van de Flask library. Na enige problemen te hebben ervaren met de schoolserver is er overgestapt op een Linux VPS van Strato (z.d.). Deze oplossing biedt meer mogelijkheden omdat er hier directe toegang is tot zaken zoals de firewall.

Webapplicatie
Na een eerste versie van de webapplicatie in React te hebben gemaakt is er ontdekt dat dit niet ging werken. Geen van de projectleden had ervaring in React en Javascript of websites maken in het algemeen. Voordat er werd begonnen met het maken van een eerste versie in React wisten we al dat niemand ervaring had in React, maar er werd toch een poging gedaan. Met behulp van het video’s en websites kwam er toch snel een eerste versie van de UI. Daarna kwam pas de echte uitdaging: functionaliteit toevoegen. Vooral de connectie maken met de API bleek erg lastig. Na veel uitzoek werk en proberen om problemen op te lossen leek het, het beste idee om opnieuw te beginnen.

De tweede (mogelijke) oplossing die geprobeerd is heet React-Admin. React-Admin is een framework gebaseerd op React en Material-UI maar specifiek gemaakt voor communicatie met API’s. Klonk veelbelovend dus. Maar na testen bleek dat toch niet geschikt was. React-Admin vereist namelijk een specifieke bouwstructuur van een API wat niet geschikt is voor de API die gebruikt wordt bij dit project. Volgende oplossing dan maar weer.

De derde (mogelijke) oplossing was Refine. Refine is ook een React Framework. Maar ook hiervoor zou de API volgens een specifieke bouwstructuur moeten zijn gemaakt. Inmiddels kwam de deadline steeds sneller inzicht en moest er toch een goede oplossing komen.

De vierde (mogelijke en veelbelovende) oplossing was Budibase. Budibase is een opensource webapplicatie builder om data apps te maken. Toen we deze oplossing wilden testen met de API werden er problemen gevonden met de schoolserver. De Firewall blokkeert namelijk verbindingen en aanvragen van buitenlandse IP-adressen blokkeert. Er is een mail gestuurd naar de serverbeheerder of hij het IP-adres van Budibase kon toelaten op de schoolserver. Deze mail is gestuurd in de week voor de kerstvakantie. Aan het eind van de kerstvakantie was er nog steeds geen antwoord en moest er een andere server geregeld worden. Dit was de server van Strato. Er kon dus getest worden met Budibase maar helaas voldeed Budibase niet aan een aantal andere eisen zoals data exporteren naar een Excel bestand. Volgende oplossing.

Inmiddels was het eind van de kerstvakantie en moest er toch echt een oplossing komen.
De vijfde (mogelijke) oplossing was Blazor samen met Radzen componenten (grafische weergave. Blazor is een framework waarin er geprogrammeerd wordt in C#. C# is een makkelijkere taal dan JavaScript en is dus sneller te begrijpen. Ook hierin is een eerste versie gemaakt maar ook in Blazor kan je geen data exporteren vanuit de API naar een Excel bestand.

De laatste (en gelukkig goede) oplossing is Microsoft Power BI. Power BI is bedoeld voor datavisualisatie en dus precies wat nodig is. Om een aantal onderdelen te gebruiken van Power BI die nodig zijn is de Pro licentie nodig, maar na overleg met onze Product Owner blijkt dat zij deze licentie heeft. De webapplicatie gaat na heel veel gedoe dus gemaakt worden in Microsoft Power BI.

(Bij vraag naar de bestanden voor de eerdere versies van de webapplicatie neem contact op met Leandro de Nijs, 1003440@hr.nl)

### Conclusie en adviezen

Uiteindelijk, na veel zoekwerk en testen, is voor dit project de beste webapplicatie Microsoft Power BI. De Hogeschool Rotterdam maakt al intensief gebruik van de programma’s van Microsoft en maakt volgens de Product Owner ook steeds meer gebruikt van Power BI. Na dit project kan de Hogeschool dus gemakkelijk de webapp overnemen om aan te passen en/of te onderhouden. Ook biedt Power BI nauwe samenwerking binnen andere Microsoftprogramma’s zoals Excel en Teams.
Voor dit Project is de beste API de REST-API in Python gebruik makend van de Flask Library. Deze API zal data ophalen uit de SQLite3 database en de data sturen naar Power BI om grafisch weer te geven.

# Bronnen

W3 Lab. (2021, 15 juli). Why You Should Choose A Web Application Over A Desktop One. Geraadpleegd op 8 oktober 2021, van https://w3-lab.com/choose-web-application-over-desktop/

Digital Skynet. (2020, 3 juni). Desktop App vs Web App: Comparative Analysis. Geraadpleegd op 8 oktober 2021, van https://digitalskynet.com/blog/Desktop-App-vs-Web-App-Comparative-Analysis

Meta. (z.d.). React – A JavaScript library for building user interfaces. React. Geraadpleegd op 8 oktober 2021, van https://reactjs.org/

MUI. (z.d.). MUI: The React component library you always wanted. Geraadpleegd op 8 oktober 2021, van https://mui.com/

TransIP. (z.d.). Wat is een REST API? | TransIP. Geraadpleegd op 8 oktober 2021, van
https://www.transip.nl/knowledgebase/artikel/2997-wat-is-een-rest-api/
VPS Linux bestellen vanaf € 5 | STRATO. (z.d.). STRATO AG. Geraadpleegd op 4 januari 2022, van
https://www.strato.nl/server/vps-linux/

React Admin. (z.d.). Open-Source Framework for B2B Applications. Geraadpleegd op 5 december 2021, van https://marmelab.com/react-admin/

refine | A React-based framework for building data-intensive applications in no time! | refine. (z.d.).
Refine. Geraadpleegd op 10 december 2021, van https://refine.dev/

budibase. (z.d.). https://budibase.com/product. Geraadpleegd op 13 december 2021, van https://budibase.com/product

Radzen benefits. (z.d.). Radzen.com. Geraadpleegd op 26 december 2021, van https://www.radzen.com/features/

# Changelog

Versie | Datum | Aanpassing | Auteur
1.0 | 18/09/2021 | Eerste versie | Leandro de Nijs
1.1 | 21/09/2021 | Deelvraag deels beantwoord | Tom van Pelt
1.2 | 26/09/2021 | Deelvraag verder beantwoord | Tom van Pelt
1.3 | 08/10/2021 | Deelvragen verder beantwoord, tabellen en afbeeldingen toegevoegd, conclusie getrokken en bronnen toegevoegd | Leandro de Nijs
1.4 | 19/11/2021 | Bronnen in APA-stijl gezet en lay-out opgeschoond | Tom van Pelt
1.5 | 10/01/2022 | Grote toevoeging | Leandro de Nijs
1.6 | 11/01/2022 | Bronnen toegevoegd | Leandro de Nijs
1.7 | 15/01/2022 | Afbeeldingen op Voorblad toegevoegd | Tom van Pelt
1.8 | 30/01/2022 | Kleine aanpassing | Leandro de Nijs
1.9 | 31/01/2022 | Kleine aanpassing | Tom van Pelt

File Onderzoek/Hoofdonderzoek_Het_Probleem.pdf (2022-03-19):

# Hoofdonderzoek: Het probleem – Project

56

Help de RDM-werkplaatsen om beter grip te krijgen op het gebruik van de werkplaatsen!


Projectleden:
- Matthijs Briel (0988991)
- Leandro de Nijs (1003440)
- Tom van Pelt (1003212)
- Gijs Kortlever (1003152)
Inleverdatum: 6 Februari 2022
Begeleiders: Erwin de Mos & S.M. Hekkelman Bedrijfsbegeleider (Product Owner): F.W.J. Joosten Gladon Gelegenheid: Eerste Kans


# Inhoudsopgave

# Wat is het probleem?

De RDM Werkplaatsen zijn te gebruiken door studenten en docenten van vijf instituten: het instituut voor Engineering and Applied Sciences (EAS), het Instituut voor de Gebouwde Omgeving (IGO), het instituut voor Communicatie, Media en Informatietechnologie (CMI), het Rotterdam Mainport Instituut (RMI) en de Rotterdam Academy (RAC). Deze vijf instituten betalen samen de werkplaatsen en de instructeurs. Maar de regisseur van de RDM Werkplaatsen heeft niet goed zicht op hoeveel elk instituut gebruikt maakt van de werkplaatsen.

Een deel van het onderwijs wordt ingeroosterd (gepland). Maar een deel van het onderwijs bestaat uit studenten die individueel (ongepland) komen werken in de werkplaatsen (vrije inloop). Op dit moment houden de instructeurs handmatig op papieren lijsten bij welke student, van welke opleiding, op welke dag de werkplaatsen komen bezoeken. Aan het einde van de maand typen ze deze handmatige lijsten over in Excel. En vervolgens worden er van acht Excellijsten (iedere werkplaats één) één totaal lijst gemaakt op basis waarvan aan het einde van het jaar de analyse gemaakt kan worden hoeveel ieder instituut gebruik heeft gemaakt van welke werkplaatsen. Dit is arbeidsintensief en foutgevoelig.

# Waarom is het probleem eigenlijk een probleem?

Aangezien het ‘oude’ systeem handmatig wordt gedaan is dit arbeidsintensief en foutgevoelig. Ook is er sprake van vrije inloop. Als er toevallig geen instructeur aanwezig is in een werkplaats moet er nog wel worden bij gehouden wie er in de werkplaats is geweest. Ook omdat het hier over grote bedragen gaat zijn fouten eigenlijk niet te veroorloven. Om dit probleem op te lossen moet er een geautomatiseerd registratiesysteem worden bedacht. Dit neemt de werklast af van de instructeurs en zorgt voor betrouwbare data waar de regisseur van de RDM Werkplaatsen op kan vertrouwen tijdens haar presentatie van de financiën.

# Hoofdvraag

- Hoe kan er een systeem gemaakt worden om studenten te registeren die van de werkplaatsen gebruik willen maken?

# Deelvragen

- Zijn er al bestaande oplossingen van een inloop registratiesysteem?
- Welke scan methode voldoet het best aan de gestelde eisen?
- Wat willen de stakeholders voor registratie methode?
- Wat wordt gezien als inloop?
- Wat moet er geregistreerd worden?
- In welke werkplaatsen moet er registratie plaats vinden?
- Wat moet er gedaan worden met de registraties?
- Met welke wet- en regelgeving moet rekening worden gehouden?

# Definition of Done

Er is een werkend prototype van een registratiesysteem voor in de werkplaatsen. Via dit systeem kan een student inchecken en wordt deze data ergens opgeslagen. Ook is er een applicatie, website of iets dergelijks waarin mevrouw Joosten-Gladon en 3 of 4 andere collega’s de data van het registratiesysteem grafisch kan zien, met als belangrijkste data de verdeling over de instituten. Een eis aan de applicatie is dat de data te exporteren is naar Excel.

# Resultaten

Om de hoofdvraag te kunnen beantwoorden zullen de deelvragen eerst moeten worden beantwoord. Om deze te beantwoorden zijn er verschillende onderzoekstechnieken gebruikt, literatuur-, experimenteel- en gebruikersonderzoek. Ook worden sommige vragen beantwoord door de product owner. De resultaten van de deelvragen zijn:

- Zijn er al bestaande oplossingen van een inloop registratiesysteem?
Deze vraag wordt uitgebreid uitgewerkt in het onderzoek “Onderzoek_Bestaande_Oplossingen.pdf”. Deze is te vinden in de map “Onderzoek => Literatuur_Onderzoek”. De uiteindelijke conclusie van het onderzoek is om het advies te geven om een aftakking van het systeem te gebruiken wat ook in de Makro wordt gebruikt, met als aanvulling de mogelijkheid tot scannen van QR-codes.
- Welke scan methode voldoet het best aan de gestelde eisen?
Deze vraag is beantwoord door verscheidende testen uit te voeren op de verschillende methodes. Deze testen en gestelde eisen zijn te vinden in het onderzoek “Test_Registratie_Methodes.pdf”. Deze staat in de map “Onderzoek => Experimenteel_Onderzoek”. De conclusie van dit onderzoek kwam uit op het gebruik van de 2D barcode scanner.
- Wat willen de stakeholders voor registratie methode?
Voor dit onderzoek moest er eerst worden bepaald wie de belangrijkste stakeholders zijn. Dit zijn de instructeurs en de studenten. Met de instructeurs zijn interviews gehouden om hun ideeën en meningen te horen. Onder de studenten is een enquête gehouden. De enquête is op verscheidene plekken opgehangen bij de RDM-campus en hebben we met de instructeurs afgesproken dat zij ook actief mensen op de enquête zouden wijzen. De resultaten van deze onderzoeken staan in het bestand “Onderzoek_Registratiemethodes.pdf” in de map “Onderzoek => Gebruikers_Onderzoek”. Uit de enquête is gekomen dat de overhand een pasjes en QR-code systeem wil.
- Wat wordt gezien als inloop?
Uit het interview met de instructeurs is gebleken dat iets alleen inloop is als er echt iets wordt gemaakt of getest. Even iets vragen of lenen wordt niet gezien als inloop. Ook zijn er twee soorten inloop: geroosterd en vrij. Deze hoeven niet van elkaar te worden onderscheiden.

- Wat moet er geregistreerd worden?
Dit staat in het onderzoek “Welke_Data_Verzamelen.pdf” in de map “Onderzoek”. Naar aanleiding van de wensen en overleg met de PO moeten studentnummer, instituut, werkplaats, opleiding en type registratie methode worden geregistreerd.
- In welke werkplaatsen moet er registratie plaats vinden?
In principe moet er in elke werkplaats registratie plaatsvinden. Er is ook een aanvullende inventarisatie gemaakt. Deze staat in het document “Werkplaats_Inventarisatie.pdf” in de map “Onderzoek”.
- Wat moet er gedaan worden met de registraties?
De registraties moeten worden bijgehouden in een database. Uit deze database worden vervolgens de registraties grafisch inzichtelijk gemaakt in Power BI. Meer hierover staat in het document “Beste_Software_voor_Registratiepaal.pdf” in de map “Onderzoek”.
- Met welke wet- en regelgeving moet rekening worden gehouden?
Dit staat in het document “Waarmee_Rekening_Houden.pdf”. Deze is te vinden in de map “Onderzoek”. Hier staan ook de overige zaken in waar rekening mee moet worden gehouden.

# Conclusie

Nu alle deelvragen zijn beantwoord kan de hoofdvraag beantwoord worden:
Hoe kan er een systeem gemaakt worden om studenten te registeren die van de werkplaatsen gebruik willen maken?

Het advies is om gebruik te maken van een 2D Code scanner, een scherm voor een grafische gebruikersinterface en een buzzer voor het duidelijk maken van een geslaagde registratie in een registratiepaal. Deze conclusie is in overeenstemming met de wensen van de PO, de instructeurs en de conclusie van de enquête onder de studenten.
De registratiepaal biedt, dankzij de gekozen scanner, twee mogelijkheden voor registratie voor de studenten en is extra toekomstbestendig voor de FIT. De registratiedata wordt opgeslagen in een database en kan grafisch worden weergegeven in een Power BI applicatie.

# Changelog

Versie | Datum | Aanpassing | Auteur
1.0 | 18/09/2021 | Eerste versie | Leandro de Nijs
1.1 | 26/09/2021 | Definition of Done toegevoegd | Leandro de Nijs
1.2 | 01/10/2021 | Hoofdvraag en deelvragen toegevoegd | Leandro de Nijs
1.3 | 08/10/2021 | Lay-out klein beetje aangepast en inhoudsopgave bijgewerkt | Tom van Pelt & Leandro de Nijs
1.4 | 19/10/2021 | Lay-out verder aangepast en tekst opgeschoond | Tom van Pelt
1.5 | 15/01/2022 | Afbeeldingen op Voorblad toegevoegd | Tom van Pelt
1.6 | 28/01/2022 | Grote aanvulling | Leandro de Nijs
1.7 | 30/01/2022 | Aanpassingen | Leandro de Nijs & Tom van Pelt
1.8 | 05/02/2022 | Laatste aanpassing | Leandro de Nijs

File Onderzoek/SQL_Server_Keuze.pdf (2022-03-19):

# Onderzoek: SQL Server Keuze – Project 56

Help de RDM-werkplaatsen om beter grip te krijgen op het gebruik van de werkplaatsen!

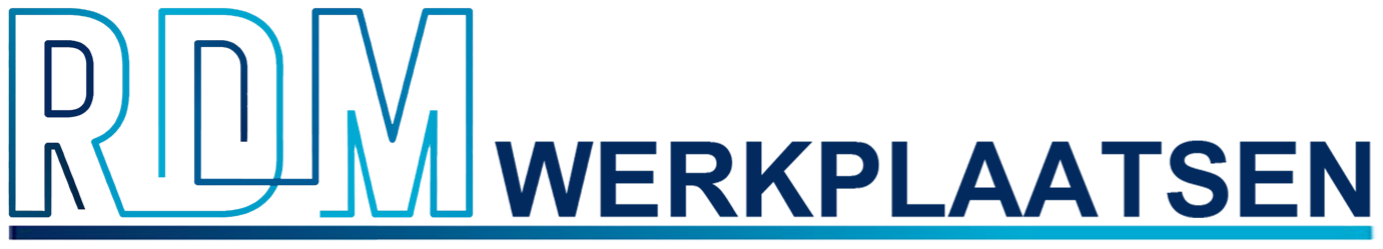
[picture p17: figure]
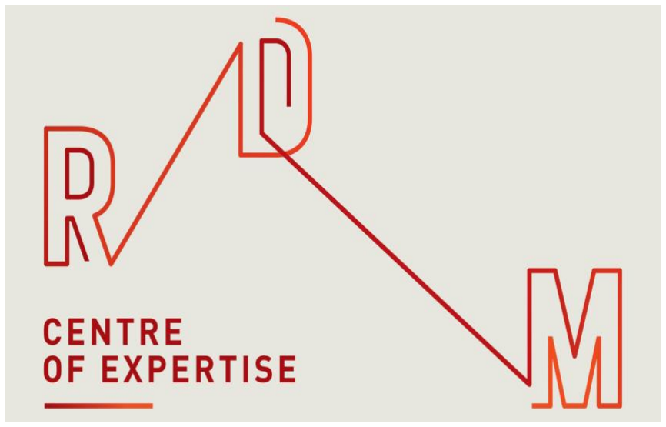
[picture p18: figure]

Projectleden:
- Matthijs Briel (0988991)
- Leandro de Nijs (1003440)
- Tom van Pelt (1003212)
- Gijs Kortlever (1003152)
Inleverdatum: 6 Februari 2022
Begeleiders: Erwin de Mos & S.M. Hekkelman Bedrijfsbegeleider (Product Owner): F.W.J. Joosten Gladon Gelegenheid: Eerste Kans

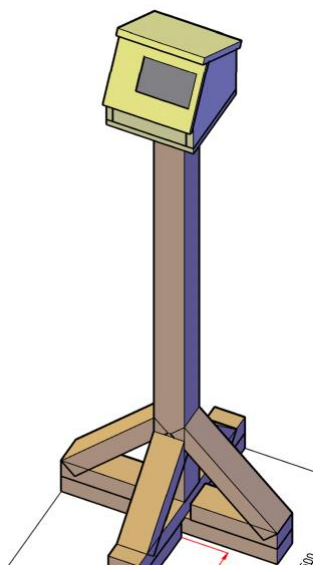
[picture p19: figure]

## Inhoudsopgave

## Inleiding

Voor onze studenten-data hebben we een opslag plek nodig. Dit gebeurt in een database, dit om efficiënt en makkelijk bij onze data te kunnen komen.

Er zijn veel verschillende aanbieders die allemaal verschillende database software maken.
In dit onderzoek filteren we hier doorheen en komen we op een database die, voor ons, bij dit project bruikbaar is.

## De criteria

- Simpele installatie
- Hoeft niet enorme hoeveelheden data aan te kunnen (Dit is een test database)
- Kan makkelijk samenwerken met een API

## De mogelijkheden

- MySQL
- Gratis.
- Goed beveiligd maar niet het beste wanneer maken van persoonsgegevens een must is.
- Oracle
- Betaald.
- Ondersteund SQL en heeft ook Block chain mogelijkheden.
- PostgreSQL
- Slecht met relationele data.
- Veel verschillende soorten indexes, zoals partial index en bloom filters.
- Microsoft SQL-server:
- Betaald.
- Werkt goed in combinatie met andere Microsoftproducten.
- Werkt met SQL & JSON.
- Mongo DB
- Een documenten database, bevat geen SQL-code.
- SQL-lite
- Is in C gegrond, er is geen sprake van een client-server relatie.
- Het heeft zwakke syntax die niet domain-integrity gegarandeerd.
- "SQLite is a popular choice as embedded database software for local/client storage in application software such as web browsers. It is arguably the most widely deployed database engine, as it is used today by several widespread browsers, operating systems, and embedded systems (such as mobile phones), among others."¹

## Conclusie

Voor onze specifieke omstandigheden is SQLite de beste database software, deze zal dan ook gebruikt gaan worden voor onze test-database. Dit komt uit een vergelijking van de verschillende databases die beschikbaar zijn en een advies dat we gekregen hebben van dhr. Jacques de Hooge.

Waar wel bij SQLite op gelet moet worden is het feit dat het datatype binnen kolommen niet vaststaat. Dit houdt in dat er binnen de code fail saves ingebouwd moeten worden om te voorkomen dat datatypes gemengd worden in kolommen.

1 https://en.wikipedia.org/wiki/SQLite

## Bronnen

Mehta, A. (2021, 7 september). Top 15 Databases to Use in 2021 and Beyond. Appinventiv. Geraadpleegd op 8 oktober 2021, van https://appinventiv.com/blog/top-web-app-database-list/

Kamaruzzaman, M. (2021, 20 januari). Top 10 Databases to Use in 2021 - Towards Data Science. Medium. Geraadpleegd op 8 oktober 2021, van https://towardsdatascience.com/top-10-databasesto-use-in-2021-d7e6a85402ba (https://towardsdatascience.com/top-10-databases-to-use-in-2021-d7e6a85402ba)

Peterson, R. (2021, 7 oktober). 13 BEST Free Database Software (SQL Databases List) in 2021. Guru99. Geraadpleegd op 8 oktober 2021, van https://www.guru99.com/free-databasesoftware.html (https://www.guru99.com/free-database-software.html)

SQLite. (z.d.). Most Widely Deployed SQL Database Engine. Geraadpleegd op 8 oktober 2021, van https://sqlite.org/mostdeployed.html

## Changelog

Versie | Datum | Aanpassing | Auteur
1.0 | 28/09/2021 | Eerste versie | Gijs Kortlever
1.1 | 30/09/2021 | Koppen toegevoegd, koppen klein beetje aangevuld en inhoudsopgave toegevoegd | Gijs Kortlever
1.2 | 05/10/2021 | Extra informatie en bronnen toegevoegd | Gijs Kortlever
1.3 | 06/10/2021 | Extra informatie, bronnen en conclusie toegevoegd | Gijs Kortlever
1.4 | 07/10/2021 | Tekst klein beetje geordend | Tom van Pelt
1.5 | 08/10/2021 | Alle koppen verder aangevuld | Gijs Kortlever
1.6 | 19/11/2021 | Lay-out aangepast en tekst opgeschoond. Bronnen in APA-stijl gezet | Tom van Pelt
1.7 | 15/01/2022 | Afbeeldingen op Voorblad toegevoegd | Tom van Pelt
1.8 | 20/01/2022 | Kleine aanpassing | Leandro de Nijs

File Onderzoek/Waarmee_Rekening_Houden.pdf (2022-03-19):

# Onderzoek: Waar moeten we rekening mee houden – Project 56

Help de RDM-werkplaatsen om beter grip te krijgen op het gebruik van de werkplaatsen!


Projectleden:
- Matthijs Briel (0988991)
- Leandro de Nijs (1003440)
- Tom van Pelt (1003212)
- Gijs Kortlever (1003152)
Inleverdatum: 6 Februari 2022
Begeleiders: Erwin de Mos & S.M. Hekkelman Bedrijfsbegeleider (Product Owner): F.W.J. Joosten Gladon Gelegenheid: Eerste Kans


# Inhoudsopgave

# Waar moet er wel/geen rekening mee gehouden worden?

- Er moet rekening worden gehouden met de AVG/FIT regelgeving. Er wordt namelijk redelijk gevoelige data opgeslagen en daar moet niet iedereen makkelijk bij kunnen.
- Ook moet er rekening worden gehouden met de wensen van de PO en de instructeurs van de werkplaatsen. De instructeurs zullen degene zijn die het vaakst met een registratiesysteem in contact komen en er moet gezorgd worden dat de werkdruk van hen juist wordt verlicht niet wordt verzwaard.
- Overigens hoeft er geen rekening worden gehouden met hoelang een student in de werkplaats aanwezig hoeft te zijn. Een student dient dus alleen ‘in te checken’ en hoeft niet uit te checken.

# Welke obstructies zijn er?

- Een redelijk grote obstructie is dat we informatie en documentatie niet krijgen van de FIT van de Hogeschool. Dit met de rede dat ze nooit productiedata aan studenten zullen overgeven. Onder productiedata valt in dit geval de database (en toebehoren) van de HR-studenten en documentatie om alle data van een schoolpas uit te lezen. Het advies van de FIT is daarom om een universeel systeem te maken, dat uiteindelijk in principe door wie dan ook geïmplementeerd kan worden, waaronder voor dit project de RDM-werkplaatsen. Om te testen raadt de FIT aan om gebruik te maken van fictieve data. Omdat het systeem universeel dient te zijn hebben moet er rekening worden gehouden met een grotere uitdaging omdat nu niet precies duidelijk is waar alle data vandaan kan komen.

# Wat zijn de regels over privacy (FIT/AVG)?

- Zoals hierboven genoemd krijgen wij geen productiedata van de FIT omdat dit security-vlak erg gevoelig ligt, uit privacy opzicht moet de hogeschool er voor zorgen dat alleen zeer bevoegde medewerkers toegang hebben tot privacy gevoelige informatie. Al zouden ze de database met studentgegevens overhandigen, dan is dat een extreme inbreuk op de privacy van alle studenten van de Hogeschool Rotterdam. Wij zijn immers geen bevoegde medewerkers van de Hogeschool Rotterdam.
Dit is wat de Kamer Van Koophandel zegt over de AVG: “De privacywet Algemene Verordening Gegevensbescherming (AVG) geldt sinds 25 mei 2018 voor de Europese Unie. Internationaal heet de wet General Data Protection Regulation (GDPR). Door de AVG heb je als ondernemer verplichtingen bij het verwerken van persoonsgegevens. Jouw klanten, medewerkers en leveranciers moeten weten welke gegevens jij van ze hebt en kunnen voor zichzelf op komen als het gaat om de verwerking van hun gegevens. Je klant kan bijvoorbeeld inzage vragen in opgeslagen data, of een eerder gegeven toestemming intrekken”
Het komt er op neer dat een consument op elk moment van welke organisatie dan ook kan bevelen om aan hun te vertellen wat die organisatie weet over de consument en vervolgens mag de consument dan ook een opdracht tot verwijdering sturen. Alle organisaties binnen de EU moeten zich hieraan houden van Mkb’ers tot multinationals. Dit betekend voor ons dat we ons aan deze wet moeten houden zodra we gegevens van klanten zouden verzamelen. Wij werken met fictieve data waardoor de regels omtrent de AVG niet van toepassing zijn.

Wij houden in ons product wel gewone privacy regels in acht, als wij data van studenten krijgen in vorm van studentnummers en mogelijk namen dan houden wij die gegevens binnen de projectgroep.

Bron: Den Breejen, A. (2021, 10 juni). Privacywetgeving AVG, wanneer ben je compliant? KVK. Geraadpleegd op 1 oktober 2021, van https://www.kvk.nl/advies-eninformatie/wetten-en-regels/privacywetgeving-avg-wanneer-ben-jecompliant/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 (https://www.kvk.nl/advies-en-informatie/wetten-en-regels/privacywetgeving-avg-wanneer-ben-je-compliant/)

# Moeten Minor studenten ook geregistreerd worden?

- Minor studenten moeten wel geregistreerd worden. Dat is niet heel moeilijk want volgens Franka krijgen de minor studenten een HR-mail adres en zijn dus echt HR-student. Misschien krijgen ze geen HR-pas, dus zouden ze niet met een HR-pas in kunnen checken bij een werkplaats. Wel hebben ze een HR-mail adres en dus een HR-account en dus een QR-code in de HR-app waarmee ze in kunnen checken bij een werkplaats.

# Wat te doen bij stroom- en/of internetuitval? (backup)

- Volgens onze PO gebeurt dit niet heel vaak. Wel zal er rekening mee worden gehouden. Met stroomuitval zal het systeem simpelweg herstarten. Wel raden we de Hogeschool Rotterdam sterk, op aanraadden van instructeur Jan, een Strompi aan. Dit is een extra module voor een Raspberry Pi die samen met een losse accu ervoor zorgt dat de Raspberry Pi veilig kan afsluiten als de voeding van de registriepaal wordt gehaald en de SD-kaart niet corrupt raakt.
- Met internetuitval is ook rekening gehouden, hier zijn namelijk schermen voor toegevoegd aan de gebruikersinterface. Mocht er geen internet zijn zal de registratiepaal dit dus ook aangeven.

# Wat te doen met studenten die meerdere opleidingen tegelijk volgen?

- Meestal heeft een student die meerdere opleidingen doet een basisopleiding. Deze moet dan geregistreerd worden. Als het moeilijk is om het voor elkaar te krijgen om een student te registreren die meerdere opleidingen doet, hoeft deze niet per se geregistreerd te worden volgens Franka. Zo’n student hoeft dan niet geregistreerd te worden omdat er maar heel weinig van deze studenten zijn en omdat het er maar heel weinig zijn heeft het eigenlijk geen invloed op de berekening van de verdeelsleutel.

# Changelog

Versie | Datum | Aanpassing | Auteur
1.0 | 18/09/2021 | Eerste versie | Leandro de Nijs
1.1 | 01/10/2021 | Extra deelvraag en antwoord toegevoegd | Leandro de Nijs
1.2 | 19/11/2021 | Lay-out veranderd en bron in APA-stijl gezet | Tom van Pelt
1.3 | 20/11/2021 | Deelvragen uit ander bestand samengevoegd in dit bestand en deels beantwoord | Tom van Pelt
1.4 | 15/01/2022 | Afbeeldingen op Voorblad toegevoegd | Tom van Pelt
1.5 | 20/01/2022 | Kleine aanpassing | Leandro de Nijs
1.6 | 28/01/2022 | Aanvulling | Leandro de Nijs
1.7 | 30/01/2022 | Aanvulling / aanpassingen | Tom van Pelt & Gijs Kortlever
1.8 | 31/01/2022 | Aanpassingen | Gijs Kortlever

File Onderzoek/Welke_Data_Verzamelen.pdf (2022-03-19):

# Onderzoek: Welke data moeten we verzamelen – Project 56

Help de RDM-werkplaatsen om beter grip te krijgen op het gebruik van de werkplaatsen!


Projectleden:
- Matthijs Briel (0988991)
- Leandro de Nijs (1003440)
- Tom van Pelt (1003212)
- Gijs Kortlever (1003152)
Inleverdatum: 6 Februari 2022
Begeleiders: Erwin de Mos & S.M. Hekkelman Bedrijfsbegeleider (Product Owner): F.W.J. Joosten Gladon Gelegenheid: Eerste Kans


# Inhoudsopgave

Wat betekenen de afkortingen van alle opleidingen en instituten die de RDM-werkplaatsen

# Moet vrije inloop van geroosterde afspraken gescheiden worden?

- Nee, volgens de PO hoeft er geen onderscheidt te worden gemaakt tussen geroosterde of niet geroosterde bezoeken. De registratie moet namelijk gebeuren op het moment dat een student gebruik maakt van een werkplaats, of dit nou geroosterd is of niet.

# Welke data moet er worden verzameld per werkplaats?

- De studenten die gebruik maken van de werkplaatsen moeten worden geregistreerd. Hiervoor wordt het studentnummer, instituut, werkplaats, opleiding en type registratie methode geregistreerd.
- Per semester moet er worden bijgehouden hoeveel studenten er bij een werkplaats zijn geweest en bij welk instituut elk student zit aangesloten.
- Data moet weer te geven zijn per instituut.
- Data moet weer te geven zijn per opleiding
- Data moet weer te geven zijn per werkplaats
- Data moet filtreerbaar zijn op datum
- De wens is ook dat de drukste tijden van de dag inzichtelijk worden.

# Wat betekenen de afkortingen van alle opleidingen en instituten die de RDM-werkplaatsen gebruiken?

https://www.hogeschoolrotterdam.nl/hogeschool/organisatie/instituten
- IPO (Industrieel Product Ontwerpen)
- BK (BouwKunde)
- ROP (Ruimtelijke Ordening en Planologie)
- WAM (WAterManagement)
- MT (Maritieme Techniek)
- RAC (Rotterdam ACademy) (instituut)
- Civ. Tech. (Civiele Techniek)
- WTB (WerkTui Bouwkunde)
- GZT (GezondheidsZorg Technologie)
- RAvB (Rotterdamse Academie van Bouwkunst)

# Changelog

Versie | Datum | Aanpassing | Auteur
1.0 | 18/09/2021 | Eerste versie | Tom van Pelt
1.1 | 24/09/2021 | Deelvragen toegevoegd en aantal deelvragen beantwoord | Tom van Pelt
1.2 | 19/11/2021 | Lay-out aangepast en tekst opgeschoond | Tom van Pelt
1.3 | 21/11/2021 | Aanvulling | Leandro de Nijs
1.4 | 15/01/2022 | Afbeeldingen op Voorblad toegevoegd | Tom van Pelt
1.5 | 20/01/2022 | Kleine aanpassing | Leandro de Nijs
1.6 | 28/01/2022 | Aanvulling | Leandro de Nijs

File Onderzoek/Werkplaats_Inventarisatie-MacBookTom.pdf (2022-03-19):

# Werkplaats Inventarisatie – Project 56

Help de RDM-werkplaatsen om beter grip te krijgen op het gebruik van de werkplaatsen!


Projectleden:
- Matthijs Briel (0988991)
- Leandro de Nijs (1003440)
- Tom van Pelt (1003212)
- Gijs Kortlever (1003152)
Inleverdatum: 6 Februari 2022
Begeleiders: Erwin de Mos & S.M. Hekkelman Bedrijfsbegeleider (Product Owner): F.W.J. Joosten Gladon Gelegenheid: Eerste Kans


# Inhoudsopgave

Wat zijn de specifieke eisen per werkplaats? | Fout! Bladwijzer niet gedefinieerd.

# Welke werkplaatsen zijn er en welke instructeur(s) horen daarbij?

Werkplaats | Instructeur(s) / Instructrice(s) | Locatie | Mailadres
Aqualab | Jan Scholtens & Willem Semp | ID.0.E04 S, ID.0.E04 W | rdmaqualab@hr.nl
Elektrolab | Robbert-Jan ’t Hoen | ID.1.111 | …
Energielab | … | ID.0.G10 | rdmenergie@hr.nl
Houtwerkplaats | Piet Brussé & Krijn Hagen & Walter Broekhuizen | ID.0.132 | rdmhout@hr.nl
Lijmlab | Harry Kapsenberg | ID.0.118 | rdmlijm@hr.nl
Materialenlab | Harry Kapsenberg | ID.0.121 | rdmmaterialen@hr.nl
Metaalwerkplaats | Arjen van den Berg | ID.0.352 | rdmmetaal@hr.nl
Mobiliteitslab | Dave Gauvin | ID.0.270 | rdmmobiliteit@hr.nl
Protolab | Justus van Veghel & Eric van Ham | ID.0.341 | rdmproto@hr.nl
(Winkel) | Eric van Ham | ID.0.152 | rdmwinkel@hr.nl

# Wanneer zijn de instructeurs aanwezig?

Werkplaats | Instructeur(s) | Aanwezigheid
Aqualab | Jan Scholtens | Bijna altijd Maandag t/m Vrijdag
| Willem Semp | Vaak als Jan Scholtens er niet is / kan.
Elektrolab | Robbert-Jan ’t Hoen | …
Energielab | … | …
Houtwerkplaats | Piet Brussé | Bijna altijd Maandag t/m Vrijdag
| Krijn Hagen | Bijna altijd Maandag t/m Vrijdag
| Walter Broekhuizen | Bijna altijd Maandag t/m Vrijdag
Lijmlab | Harry Kapsenberg | Altijd dicht, tenzij er iets ingeroosterd staat.
Materialenlab | Harry Kapsenberg | Maandag t/m woensdag (’s ochtends) open.
Metaalwerkplaats | Arjen van den Berg | Bijna altijd Maandag t/m Vrijdag, soms woensdag ochtend niet.
Mobiliteitslab | Dave Gauvin | …
Protolab | Justus van Veghel | Als Eric er niet is. Soms samen.
| Eric van Ham | Als Justus er niet is. Soms samen.
(Winkel) | Eric van Ham | …

# Hoeveel in- en uitgangen zijn er per werkplaats?

Werkplaats | Ingang(en) | Uitgang(en)
Aqualab | 1 | 1
Elektrolab | … | …
Energielab | … | …
Houtwerkplaats | 1 | 1
Lijmlab | 1 | 1
Materialenlab | 1 (eventueel 2 scanners) | 1
Metaalwerkplaats | 2 | 3
Mobiliteitslab | 1 | 1
Protolab | 4 (1 hoofdingang) | 4
(Winkel) | … | …

# Is er veel vrije inloop of wordt er veel gereserveerd (per werkplaats)?

Werkplaats | Vrije Inloop (schaal 1 t/m 5)¹ | Gereserveerd (schaal 1 t/m 5)¹
Aqualab | 1 | 4
Elektrolab | … | …
Energielab | 0 | 5
Houtwerkplaats | 4-5 | 1-2
Lijmlab | 0 | 5
Materialenlab | 1-2 | 3-4
Metaalwerkplaats | 3-4 | 3-4 (ook veel geroosterd)
Mobiliteitslab | 2-3 | 3
Protolab | 4-5 | (2)
(Winkel) | … | …

# Hoe druk is het per werkplaats?

Werkplaats | Drukte (schaal 1 t/m 5)¹
Aqualab | 2
Elektrolab | 1
Energielab | 1
Houtwerkplaats | 4-5
Lijmlab | 1
Materialenlab | 2
Metaalwerkplaats | 4
Mobiliteitslab | 3
Protolab | 4-5
(Winkel) | …

1 1 = erg rustig, 5 = erg druk

# Changelog

Versie | Datum | Aanpassing | Auteur
1.0 | 04/10/2021 | Eerste versie | Tom van Pelt
1.1 | 19/11/2021 | Lay-out aanpassingen | Tom van Pelt
1.2 | 20/11/2021 | Kleine aanpassing aan deelvragen en toevoeging deelvraag met antwoord | Tom van Pelt
1.3 | 15/01/2022 | Afbeeldingen op Voorblad toegevoegd | Tom van Pelt
1.4 | 20/01/2022 | Overbodige tabel weggehaald | Tom van Pelt

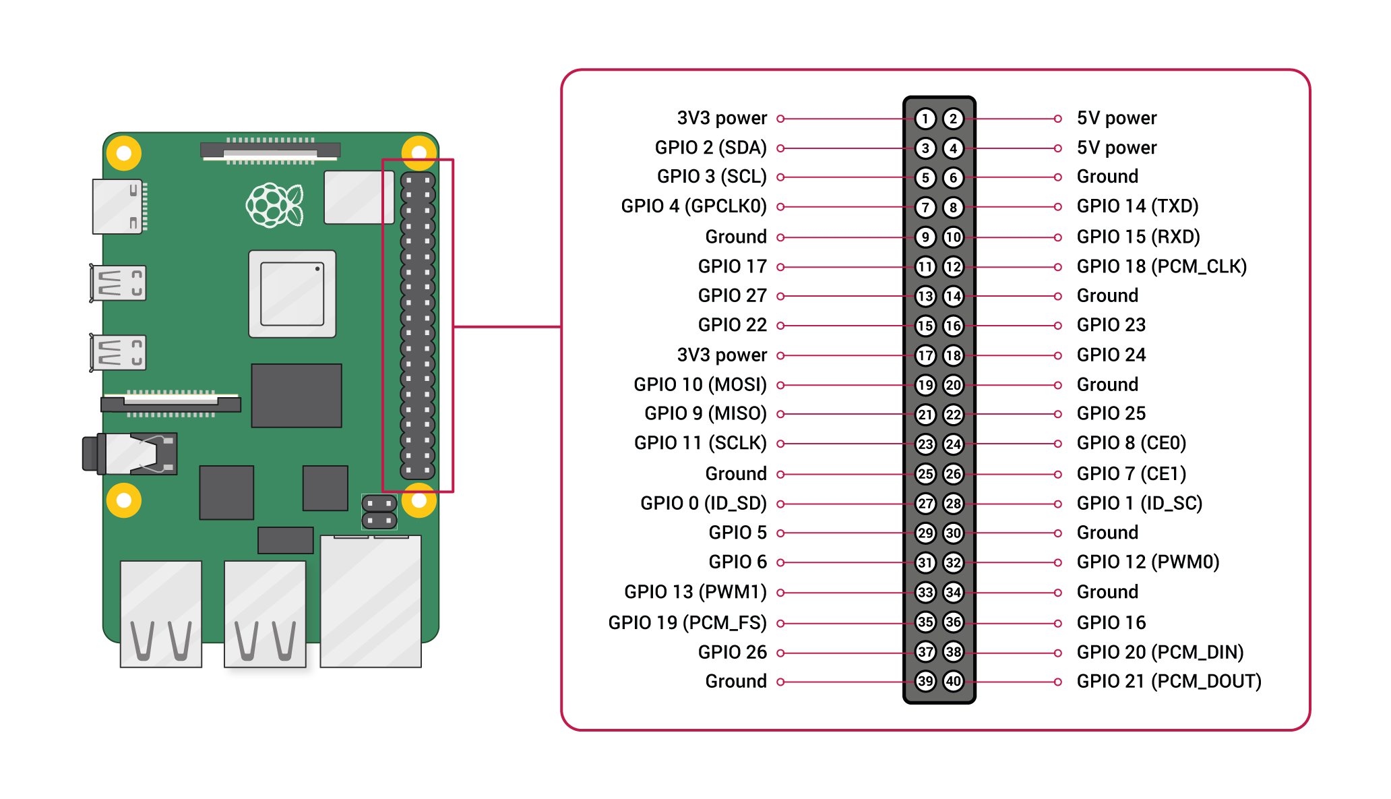
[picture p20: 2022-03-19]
Datasheets_en_Handleidingen/Raspberry_Pi_3-4_Pinout.png

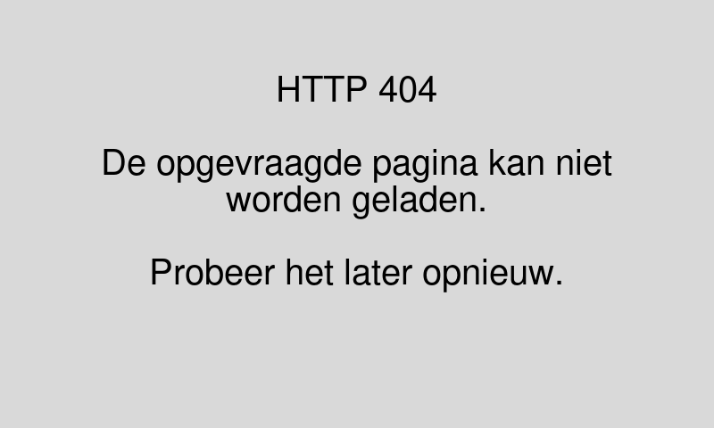
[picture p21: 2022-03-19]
Ontwerpen_en_Schema's/GUI_Schermen/HTTP_404_Errorscreen-GUI.png

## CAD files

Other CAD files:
Ontwerpen_en_Schema's/3D-Ontwerp/Registratiepaal.dwg

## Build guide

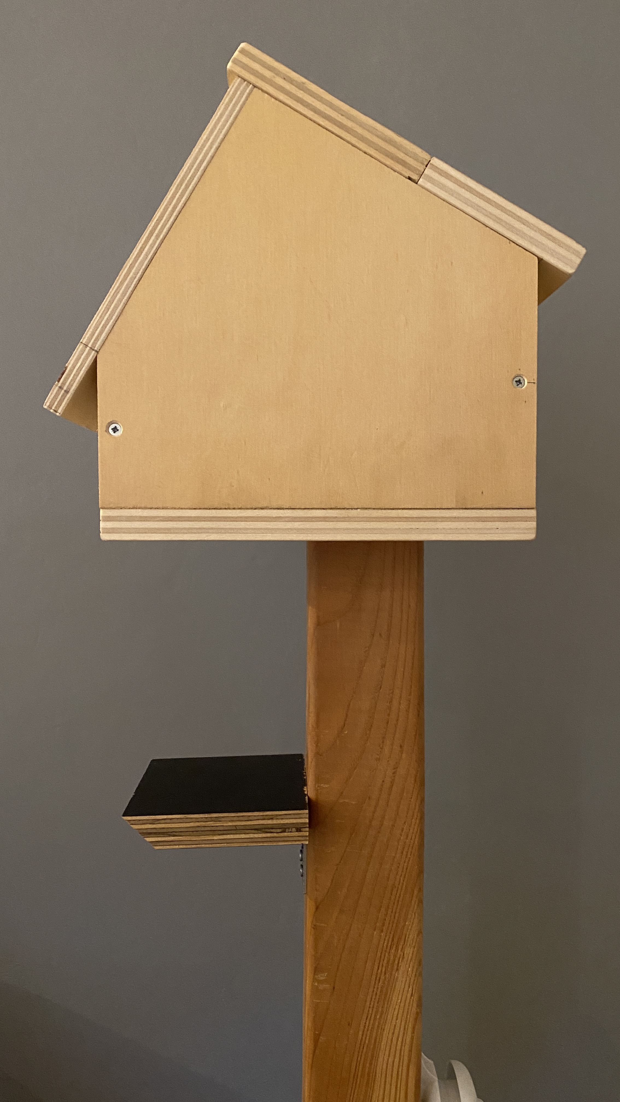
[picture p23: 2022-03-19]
How_To_Build_Your_Own_Registratiesysteem/Detail_Foto's/927E91E0-0983-4BA1-93FA-09CD03670BF3.jpeg

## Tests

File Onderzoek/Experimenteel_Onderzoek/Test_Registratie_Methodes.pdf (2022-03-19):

# Experimenteel onderzoek: Registratiemethodes– Project 56

Help de RDM-werkplaatsen om beter grip te krijgen op het gebruik van de werkplaatsen!


Projectleden:
- Matthijs Briel (0988991)
- Leandro de Nijs (1003440)
- Tom van Pelt (1003212)
- Gijs Kortlever (1003152)
Inleverdatum: 6 Februari 2022
Begeleiders: Erwin de Mos & S.M. Hekkelman Bedrijfsbegeleider (Product Owner): F.W.J. Joosten Gladon Gelegenheid: Eerste Kans


# Inhoudsopgave

Welke methode(s) kan/kunnen er gebruikt worden voor het inchecken bij de werkplaatsen op de

# Welke methode(s) kan/kunnen er gebruikt worden voor het inchecken bij de werkplaatsen op de RDM?

Er zijn een aantal methodes die handig zijn om te gebruiken voor het inchecken. Deze methodes zijn een QR-code-, barcode-, en RFID-scanner. Deze methodes hebben verschillende redenen waarom ze handig zijn om te gebruiken.

### HR-app QR-code

De QR-code scanner is handig, omdat elke student deze QR-code met zijn/haar studentnummer kan opvragen in de HR-app. Elke HR-student die gebruik wil maken van de werkplaatsen heeft immers een HR-account die gebruikt kan worden om in te loggen op de HR-app.

### HR-pas Barcode

Ook heeft elke HR-student een HR-pas. Op deze pas staat een barcode die gescand kan worden. Deze barcode bevat het studentnummer van de student.

### HR-pas RFID-chip

In de pas zit ook nog een RFID-chip die uitgelezen kan worden. De data op deze chip is echter geblokkeerd en kan dus niet worden gebruikt. Er kan alleen een card-UID (unieke code voor elke pas) uitgelezen worden. Deze code is alleen nuttig als deze ook gekoppeld kan worden aan het studentnummer via de HR-database.

# Wat zijn de voor- en nadelen van de HR-app en HR-pas?

### HR-pas

Voordelen: | Nadelen:
Elke reguliere student heeft hem. | Een student kan een andere student zijn pas gebruiken.
Is handzaam. | Schoolpas kan kwijt zijn.
Is persoon specifiek. | Schoolpas nog niet in bezit van student.
| Schoolpas wordt gebruikt voor bijv. huren van een stekkerblok.

### HR-app

Voordelen: | Nadelen:
QR-code met studentnummer in de HR-app. | Telefoon kan vergeten zijn.
Is persoon specifiek. | Telefoon kan leeg zijn.
Iedereen heeft bijna altijd een telefoon met de HR-app bij zich. | Telefoon is stuk.
| HR-app niet geïnstalleerd op telefoon en telefoon heeft geen internet om deze app te downloaden.

# Wat zijn de voor- en nadelen van de systemen?

### RFID-chip in HR-pas

Voordelen: | Nadelen:
Erg makkelijk te gebruiken. | RFID-chip niet uit te lezen zonder authenticatie token. Hierdoor dus alleen card-UID.
Meeste mensen gewend om met zo’n systeem te werken (ov-systeem). | Moet op een exacte plaats worden gehouden om te worden uit te worden gelezen.

Redelijk goedkope hardware.
Redelijk simpele software.

### Barcode op HR-pas met camera

Voordelen: | Nadelen:
Makkelijk te gebruiken. | Barcode is klein op de pas, dus moeilijker uit te lezen.
Studentnummer direct uitlezen. | Barcode is op sommige passen niet goed gedrukt en dus (bijna) niet uit te lezen.
Te combineren met QR-code | Dure hardware nodig.
| Software kan ingewikkeld worden.
| Vereist heel veel belichting op de pas

### QR-code uit HR-app met camera

Voordelen: | Nadelen:
Makkelijk te gebruiken. | Hardware kan prijzig worden als er goede kwaliteit hardware nodig is.
Studentnummer direct uitlezen. | Redelijk ingewikkelde software.
Werkt snel als hardware goed is ingesteld.
Te combineren met barcode

### Barcode op HR-pas met 2D-scanner

Voordelen: | Nadelen:
Makkelijk te gebruiken. | Barcode is klein op de pas, dus moeilijker uit te lezen.
Studentnummer direct uitlezen. | Barcode is op sommige passen niet goed gedrukt en dus (bijna) niet uit te lezen.
Te combineren met QR-code | Vereist redelijk wat licht.

### QR-code uit HR-app met 2D-scanner

Voordelen: | Nadelen:
Makkelijk te gebruiken. | Hardware kan prijzig worden als er goede kwaliteit hardware nodig is.

Studentnummer direct uitlezen.
Werkt snel omdat scherm belicht is.
Te combineren met barcode

# Testen

### Vraagstelling

- Wat is de snelste scan methode (scanner) voor studenten om zich te registreren als ze de werkplaatsen willen gebruiken?
- Wat is de betrouwbaarste scan methode (scanner) voor studenten om zich te registreren als ze de werkplaatsen willen gebruiken?

### Verschillende registratie methodes

- RFID-scanner met HR-pas
- 2D barcode scanner met HR-pas en QR-code in HR-app
- Camera scanner met HR-pas en QR-code in HR-app

### Meetopstelling & meetinstrumenten

- Meetinstrumenten:
- HR-pas (barcode op pas en RFID-chip)
- QR-code in HR-app
- Raspberry Pi 3b, 4 en Pico
- Raspberry Pi Camera V2 module
- WaveShare 2D Code scanner
- Test Software en Laptop en/of PC
- Kabels, buzzer, LEDje, etc.
- RFID-scanner: Voor het testen van de RFID-scanner is er gebruik gemaakt van een Raspberry Pi PICO, dit is een microcontroller die code draait geschreven in Python. Aan de Raspberry Pi PICO zit een LED-lampje aangesloten, een buzzer en een RIFD-scanner. De code leest het Card-UID van een RFID kaart. Als het uitlezen is geslaagd komt er een luide toon uit de buzzer en gaat het LED-lampje branden.
- 2D Code scanner: Voor het testen van de 2D Code Scanner is er gebruik gemaakt van een Raspberry Pi 3b, een buzzer, een 5 inch schermpje en de benodigde kabels. Aan de Raspberry Pi 3b is een buzzer aangesloten die piept als er succesvol gescand is. De Scanner is aangesloten op de Pi met een Micro USB naar USB-kabel. De Scanner is ingesteld op ‘Sensing Mode’. Dat betekent dat de Scanner automatisch aangaat als die een verandering in licht ziet.
- Camera scanner: Voor het testen van de Camera Scanner is er een gebruik gemaakt van een Raspberry Pi 4, een buzzer, breadboard, 24 inch beeldscherm, LEDje en de benodigde kabels. Aan de Raspberry Pi is een Rood LEDje vastgemaakt welke voor 0.5 seconde aangaat als er een succesvolle scan is. Ook zit er een Raspberry Pi V2 camera aangesloten op de Pi 4. De code die op de Pi 4 draait kan via het videobeeld van de camera barcodes en QR-codes herkennen en uitlezen. Als een barcode of QR-code is uitgelezen wordt deze data in een CSV-bestand gezet om nader te bekijken. Ook wordt er in de code gebruik gemaakt van prints om te kijken of de code correct is uitgelezen.

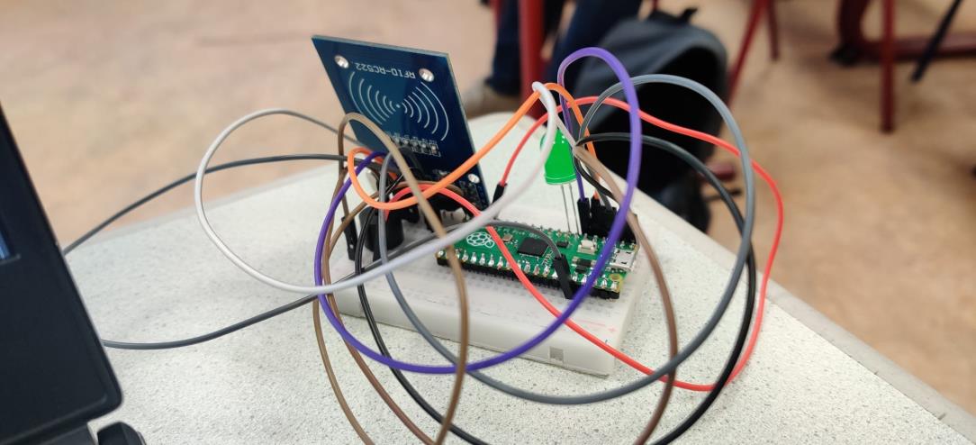
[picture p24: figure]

Figuur 1 – Test Opstelling RFID-Scanner

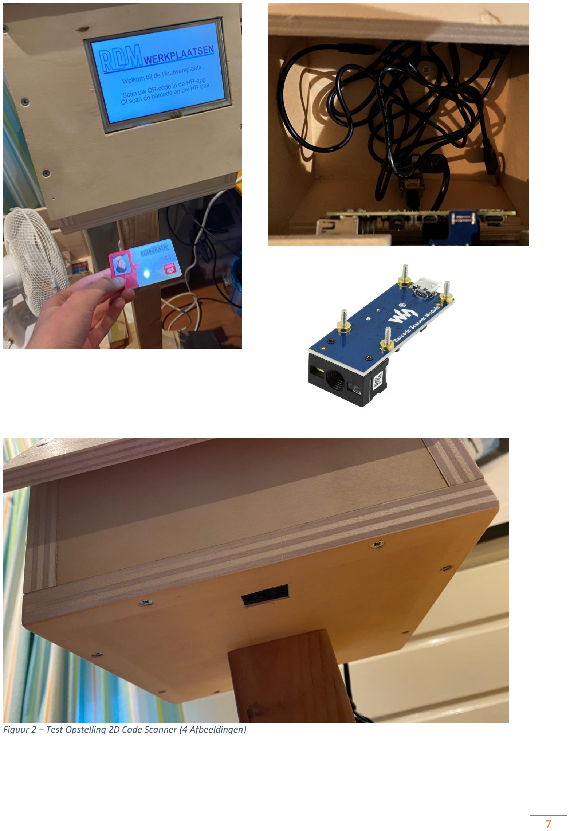
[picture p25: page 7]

Figuur 2 – Test Opstelling 2D Code Scanner (4 Afbeeldingen)

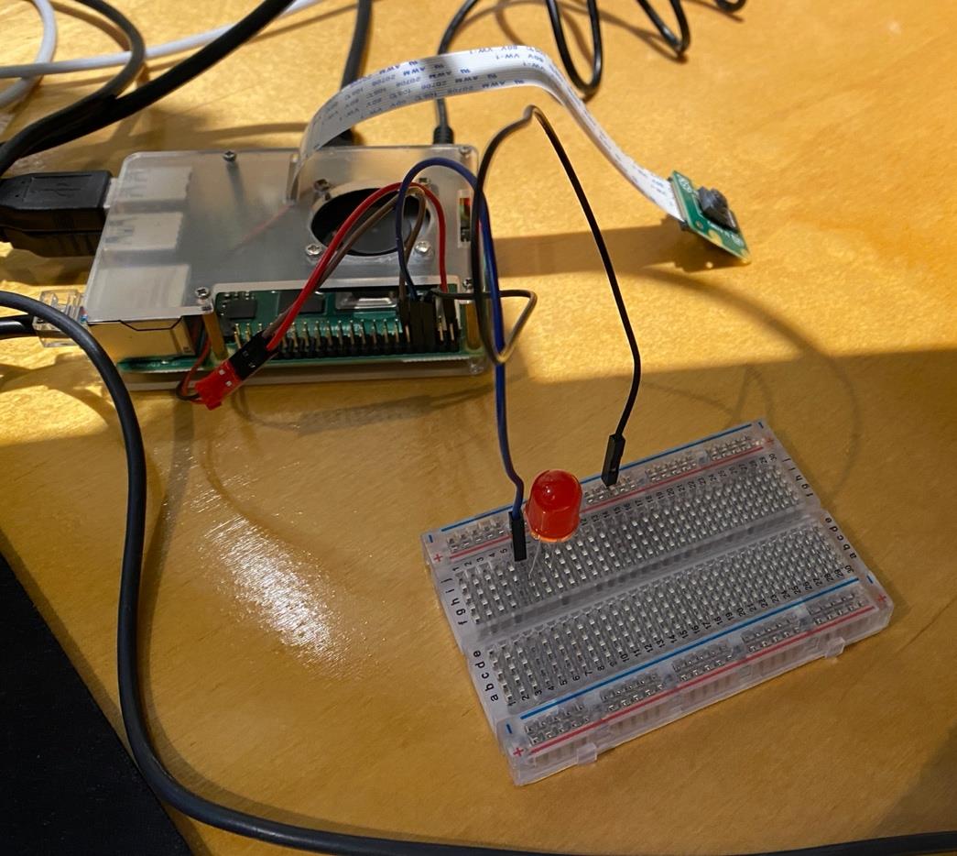
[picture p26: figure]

Figuur 3 – Test Opstelling Camera Scanner

### Externe voorwaarden

- Voldoende licht om code te kunnen lezen.
- HR-pas testen die ook in het echt gebruikt gaat worden.
- QR-code testen die ook in het echt gebruikt gaat worden.

### Te verrichten handelingen (hoe vaak)

- RFID-chip in HR-pas 100 keer scannen met RFID-scanner.
- Barcode op HR-pas 100 keer scannen met 2D Code scanner.
- Barcode op HR-pas 100 keer scannen met Camera scanner.
- QR-code in HR-app 100 keer scannen met 2D Code scanner.
- QR-code in HR-app 100 keer scannen met Camera scanner.

### Vast te leggen data

- Gemiddelde tijd voor het uitlezen van een QR-Code, Barcode of RFID-chip in milliseconden bepaalt door een timer in de code.
- Aantal successen (scan is gelukt) in hele getallen.
- Aantal gefaalde scans in hele getallen.
- Is de test geslaagd (ja of nee).
- Korte uitleg waarom test wel of niet geslaagd is.

### Requirements

- Bij 100 keer scannen wordt het te scannen object minstens 99 correct uitgelezen.
- Het uitlezen van een object gebeurt binnen 1 seconde.
- Er wordt duidelijk gemaakt dat een object correct is uitgelezen met bijvoorbeeld een buzzer, LED en/of print Lines.

### Waarnemingen

Scanner | Code Type | Geslaagd (aantal) | Gefaald (aantal) | Gemiddelde tijd voor uitlezen | Test Gehaald | Waarom wel / niet test gehaald?
2D Barcode Scanner | QR-code | 100 | 0 | ± 300 ms | Ja | De QR-code is 100/100 keer succesvol gescand en de gemiddelde tijd voor uitlezen zit ruim onder te tijd voorwaarde.
| Barcode | 99 | 1 | ± 700 ms | Ja | De Barcode werd 99/100 keer goed gescand. Ook valt hij binnen de tijd van scannen. De scan is één keer gefaald doordat de gescande barcode niet helemaal correct gedrukt is op de pas.
Camera Scanner | QR-Code | 100 | 0 | ± 2863 ms / 100 = 28,63 ms | Ja | De QR-Code werd 100/100 keer goed gescand. Ook wordt de code erg snel gescand. Deze scanner zou dus zeer goed geschikt zijn voor het scannen van QR-codes.

| Barcode | 58 | 42 | ± 39267 ms / 100 = 392,67 ms | Nee | De Barcode werd 58/100 keer goed gescand. Dat is een erg slecht resultaat. De tijd is wel snel, maar alsnog is de scanner niet geschikt voor het scannen van barcodes.
RFID Scanner | N.v.t. | 99 | 1 | ± 400 ms | Ja | De RFID-scanner heeft 99/100 keer de chip goed uitgelezen. Eén enkele keer kwam er een authenticatie error.

### Analyse

- Er wordt bepaald of een type scanner voldoet aan de gestelde eisen.
- De analyse wordt gemaakt aan de hand van het aantal correcte codes (UID of bar/QR-code) die wordt uitgelezen en de tijdsduur om een code uit te lezen.
- Er zal 100 keer worden gescand met de verschillende methodes. Van deze 100 moeten er minimaal 99 correct worden uitgelezen. Deze 100 uitlezingen wordt in Excel gezet op te kijken of ze allemaal hetzelfde zijn. Uiteindelijk wordt van de gefaalde uitlezingen een percentage bepaalt over het totaal.
| 2D barcode | 2D QR-code | Camera barcode | Camera QR-code | RFID
Percentage gefaald | 1% | 0% | 42% | 0% | 1%
- Ook zal de gemiddelde tijd worden berekend die het duurt voor het uitlezen van een scan. Dit wordt gedaan door de methode weer 100 keer te testen en de starttijd van de eindtijd (100ste is geweest) af te trekken. Dit getal zal worden gedeeld door het aantal uitlezingen (100), hierdoor wordt het aantal milliseconden bepaalt dat het duurt voor een scan.
- Ook zal er een (audio-) visuele analyse worden gemaakt om te kijken of de LED gaat branden en/of de buzzer geluid maakt.

### RFID op HR-pas

- De code voor het uitlezen werkt erg simpel. Elke RFID pas heeft een Card-UID, dit is een unieke code van elke pas. Via onze testcode (zie bijlage) kan deze worden uitgelezen. Wel moet de HR-pas goed bij de scanner worden gehouden anders kan de scanner hem niet/verkeerd uitlezen. De code leest 100 maal de pas af en bepaalt ook gelijk de tijd die het duurt voor een scan.

### Camera Scanner met Barcode en QR-code

- De software van de camera scanner werkt als volgt: de software opent de camera als videostream en scant continu in een while loop voor barcodes en QR-codes. Als de software een van deze codes detecteert leest hij hem uit, print de data op het scherm en schrijft de data naar een CSV-bestand voor nader onderzoek.
- De Scanner werkt erg goed en snel bij QR-Codes maar bij barcodes een stuk minder, omdat de camera niet goed de witte achtergrond tussen de zwarte barcodestrepen kan lezen met weinig licht. Er moet dus te allen tijde een felle lamp op de barcode schijnen en de barcode moet goed in de focus zijn van de camera (de camera heeft namelijk geen auto focus).

### 2D Scanner met Barcode en QR-Code

- De software van deze scanner is totaal niet ingewikkeld. Als de scanner een barcode of QR-code ‘herkent’ en uitleest, ‘typt’ hij het als het ware in op de computer waarop de scanner is aangesloten. De code hoeft dus alleen typ invoer te ontvangen om de data uit te lezen en dus om te kunnen kijken of de code correct is gescand.
- De testopstelling is alleen niet erg optimaal omdat de scanner al geïmplementeerd (gelijmd) zit in de registratiepaal, zoals op de foto’s te zien is. Een optimale opstelling zou zijn dat de scanner niet geïmplementeerd zit.
- Wel zijn er continu dezelfde omstandigheden zoals licht hoeveelheid.
- De scanner werkt erg goed met QR-codes en barcodes. In eerste instantie werd gedacht dat de scanner redelijk traag was (gemiddeld 2 seconden voor scannen), maar dat kwam door een vergeten sleep in de code. Toen deze sleep weggehaald was, was de scanner redelijk snel.

# Conclusie

Als er alleen gekeken zou worden naar de tijd die het duurt om een object uit te lezen zou de camera scanner in combinatie met een QR-code de beste optie zijn. De camera module in combinatie met een QR-code is ook nog eens heel betrouwbaar, echter de camera module in combinatie met een barcode is dan weer zeker niet betrouwbaar. Slechts 58% van de gescande barcodes was correct gescand en was vergeleken de andere methodes ook niet heel snel. De 2D scanner daarentegen deed het heel goed. Bij de barcode en QR-code test waren er nauwelijks foutieve uitlezingen. Ook waren de QR-code en barcode gemiddeld best snel gescand en voldeden hier dus ook aan de gestelde eis. De RFID-scanner was ook heel betrouwbaar en ook best vlot. Immers biedt de 2D barcode scanner meer mogelijkheden, namelijk barcode en QR-code. Hierdoor adviseren wij om de 2D barcode scanner te gebruiken als registratie methode.

# Changelog

Versie | Datum | Aanpassing | Auteur
1.0 | 18/10/2021 | Eerste versie | Tom van Pelt
1.1 | 01/11/2021 | Tekst scanner weggehaald en ‘Testen’ toegevoegd | Tom van Pelt & Leandro de Nijs
1.2 | 05/11/2021 | ‘Testen’ aangevuld | Tom van Pelt
1.3 | 16/11/2021 | Kleine lay-out aanpassingen | Tom van Pelt & Matthijs Briel
1.4 | 20/11/2021 | Kleine lay-out aanpassingen, inhoudsopgave gewijzigd / aangevuld en figuur ingevoegd | Tom van Pelt
1.5 | 15/01/2022 | Afbeeldingen op Voorblad toegevoegd | Tom van Pelt
1.6 | 18/01/2022 | Aanvulling | Leandro de Nijs & Tom van Pelt
1.7 | 19/01/2022 | Verdere aanvulling van tekst en afbeeldingen | Tom van Pelt & Leandro de Nijs
1.8 | 20/01/2022 | Kleine aanpassing | Leandro de Nijs
1.9 | 21/01/2022 | Aanvullingen en conclusie toegevoegd | Leandro de Nijs & Tom van Pelt

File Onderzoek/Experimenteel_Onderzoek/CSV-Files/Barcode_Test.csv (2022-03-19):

2022-01-18 19:40:12.720300 | 166790 | I25
2022-01-18 19:40:16.531622 | 1005212 | CODE39
2022-01-18 19:40:16.784577 | 1005212 | CODE39
2022-01-18 19:40:16.855590 | 1003212 | CODE39
2022-01-18 19:40:16.902214 | 1005212 | CODE39
2022-01-18 19:40:16.932338 | 1005212 | CODE39
2022-01-18 19:40:16.957677 | 1005212 | CODE39
2022-01-18 19:40:18.384237 | 1005212 | CODE39
2022-01-18 19:40:18.409978 | 1003212 | CODE39
2022-01-18 19:40:18.462487 | 1005212 | CODE39
2022-01-18 19:40:18.488384 | 1005212 | CODE39
2022-01-18 19:40:19.847548 | 1003212 | CODE39
2022-01-18 19:40:20.408662 | 1005212 | CODE39
2022-01-18 19:40:26.689726 | 1009212 | CODE39
2022-01-18 19:40:27.024235 | 1006212 | CODE39
2022-01-18 19:40:27.048731 | 1006212 | CODE39
2022-01-18 19:40:27.073349 | 1003212 | CODE39
2022-01-18 19:40:27.165759 | 1003212 | CODE39
2022-01-18 19:40:27.257926 | 1003212 | CODE39
2022-01-18 19:40:27.281272 | 1003212 | CODE39
2022-01-18 19:40:27.304825 | 1003212 | CODE39
2022-01-18 19:40:27.330340 | 1003212 | CODE39
2022-01-18 19:40:27.354361 | 1003212 | CODE39
2022-01-18 19:40:28.680463 | 1003212 | CODE39
2022-01-18 19:40:28.704774 | 1003212 | CODE39
2022-01-18 19:40:28.728316 | 1003212 | CODE39
2022-01-18 19:40:29.227302 | 1003212 | CODE39
2022-01-18 19:40:29.321270 | 100%212 | CODE39
2022-01-18 19:40:29.504669 | 1003212 | CODE39
2022-01-18 19:40:29.577303 | 1005212 | CODE39
2022-01-18 19:40:29.602445 | 1003212 | CODE39
2022-01-18 19:40:29.962084 | 1003212 | CODE39
2022-01-18 19:40:29.985933 | 1003212 | CODE39
2022-01-18 19:40:30.123056 | 1003212 | CODE39
2022-01-18 19:40:31.247748 | 1003212 | CODE39
2022-01-18 19:40:31.430660 | 1003212 | CODE39
2022-01-18 19:40:31.454525 | 1003212 | CODE39
2022-01-18 19:40:31.591901 | 100%212 | CODE39
2022-01-18 19:40:31.617113 | 100%212 | CODE39
2022-01-18 19:40:31.665804 | 1003212 | CODE39
2022-01-18 19:40:31.852622 | 1006212 | CODE39
2022-01-18 19:40:31.876404 | 1006212 | CODE39
2022-01-18 19:40:32.538064 | 1006212 | CODE39
2022-01-18 19:40:32.629281 | 1003212 | CODE39
2022-01-18 19:40:33.374143 | 1006212 | CODE39
2022-01-18 19:40:33.398274 | 1006212 | CODE39
2022-01-18 19:40:33.423757 | 1006212 | CODE39
2022-01-18 19:40:33.447865 | 1006212 | CODE39
2022-01-18 19:40:33.472496 | 1006212 | CODE39
2022-01-18 19:40:33.679950 | 1005212 | CODE39
2022-01-18 19:40:33.704389 | 1005212 | CODE39
2022-01-18 19:40:34.086251 | 1006212 | CODE39
2022-01-18 19:40:34.109761 | 1006212 | CODE39
2022-01-18 19:40:34.157074 | 1006212 | CODE39
2022-01-18 19:40:34.181818 | 1006212 | CODE39
2022-01-18 19:40:34.208841 | 1006212 | CODE39
2022-01-18 19:40:34.324754 | 1003212 | CODE39
2022-01-18 19:40:35.020100 | 1006212 | CODE39
2022-01-18 19:40:35.044503 | 1006212 | CODE39
2022-01-18 19:40:35.068077 | 1006212 | CODE39
2022-01-18 19:40:35.114376 | 1003212 | CODE39
2022-01-18 19:40:35.138999 | 1003212 | CODE39
2022-01-18 19:40:35.189346 | 1003212 | CODE39
2022-01-18 19:40:35.212529 | 1003212 | CODE39
2022-01-18 19:40:35.239432 | 1003212 | CODE39
2022-01-18 19:40:35.294342 | 1006212 | CODE39
2022-01-18 19:40:35.475636 | 1003212 | CODE39
2022-01-18 19:40:35.699832 | 1003212 | CODE39
2022-01-18 19:40:35.723395 | 1003212 | CODE39
2022-01-18 19:40:37.346168 | 1003212 | CODE39
2022-01-18 19:40:37.405859 | 1003212 | CODE39
2022-01-18 19:40:37.436828 | 1003212 | CODE39
2022-01-18 19:40:37.803207 | 1006212 | CODE39
2022-01-18 19:40:37.827938 | 1006212 | CODE39
2022-01-18 19:40:37.875542 | 1003212 | CODE39
2022-01-18 19:40:38.105314 | 1003212 | CODE39
2022-01-18 19:40:38.133427 | 1003212 | CODE39
2022-01-18 19:40:38.162767 | 1003212 | CODE39
2022-01-18 19:40:38.194159 | 1003212 | CODE39
2022-01-18 19:40:38.224915 | 1003212 | CODE39
2022-01-18 19:40:38.254919 | 1003212 | CODE39
2022-01-18 19:40:38.311238 | 1003212 | CODE39
2022-01-18 19:40:38.344385 | 1003212 | CODE39
2022-01-18 19:40:38.375230 | 1003212 | CODE39
2022-01-18 19:40:38.407852 | 1003212 | CODE39
2022-01-18 19:40:38.440759 | 1003212 | CODE39
2022-01-18 19:40:38.472395 | 1003212 | CODE39
2022-01-18 19:40:38.536602 | 1003212 | CODE39
2022-01-18 19:40:38.567306 | 1003212 | CODE39
2022-01-18 19:40:38.600222 | 1003212 | CODE39
2022-01-18 19:40:39.669130 | 1003212 | CODE39
2022-01-18 19:40:39.721564 | 1003212 | CODE39
2022-01-18 19:40:39.754188 | 1003212 | CODE39
2022-01-18 19:40:39.783983 | 1006212 | CODE39
2022-01-18 19:40:39.814351 | 1003212 | CODE39
2022-01-18 19:40:39.844881 | 1006212 | CODE39
2022-01-18 19:40:39.878411 | 1003212 | CODE39
2022-01-18 19:40:39.908167 | 1003212 | CODE39
2022-01-18 19:40:39.996379 | 1006212 | CODE39
2022-01-18 19:40:40.078167 | 1006212 | CODE39

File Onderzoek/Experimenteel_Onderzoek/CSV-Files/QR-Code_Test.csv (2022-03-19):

2022-01-18 19:36:09.159156 | 1003212 | QRCODE
2022-01-18 19:36:09.374791 | 1003212 | QRCODE
2022-01-18 19:36:09.407561 | 1003212 | QRCODE
2022-01-18 19:36:09.434864 | 1003212 | QRCODE
2022-01-18 19:36:09.462761 | 1003212 | QRCODE
2022-01-18 19:36:09.493875 | 1003212 | QRCODE
2022-01-18 19:36:09.541313 | 1003212 | QRCODE
2022-01-18 19:36:09.576947 | 1003212 | QRCODE
2022-01-18 19:36:09.609756 | 1003212 | QRCODE
2022-01-18 19:36:09.634941 | 1003212 | QRCODE
2022-01-18 19:36:09.665590 | 1003212 | QRCODE
2022-01-18 19:36:09.698140 | 1003212 | QRCODE
2022-01-18 19:36:09.723982 | 1003212 | QRCODE
2022-01-18 19:36:09.755407 | 1003212 | QRCODE
2022-01-18 19:36:09.788024 | 1003212 | QRCODE
2022-01-18 19:36:09.816976 | 1003212 | QRCODE
2022-01-18 19:36:09.847592 | 1003212 | QRCODE
2022-01-18 19:36:09.887667 | 1003212 | QRCODE
2022-01-18 19:36:09.918874 | 1003212 | QRCODE
2022-01-18 19:36:09.948789 | 1003212 | QRCODE
2022-01-18 19:36:09.973680 | 1003212 | QRCODE
2022-01-18 19:36:10.009671 | 1003212 | QRCODE
2022-01-18 19:36:10.035960 | 1003212 | QRCODE
2022-01-18 19:36:10.064476 | 1003212 | QRCODE
2022-01-18 19:36:10.091856 | 1003212 | QRCODE
2022-01-18 19:36:10.117373 | 1003212 | QRCODE
2022-01-18 19:36:10.141582 | 1003212 | QRCODE
2022-01-18 19:36:10.170367 | 1003212 | QRCODE
2022-01-18 19:36:10.195275 | 1003212 | QRCODE
2022-01-18 19:36:10.220808 | 1003212 | QRCODE
2022-01-18 19:36:10.249119 | 1003212 | QRCODE
2022-01-18 19:36:10.275265 | 1003212 | QRCODE
2022-01-18 19:36:10.298324 | 1003212 | QRCODE
2022-01-18 19:36:10.323111 | 1003212 | QRCODE
2022-01-18 19:36:10.345441 | 1003212 | QRCODE
2022-01-18 19:36:10.371896 | 1003212 | QRCODE
2022-01-18 19:36:10.393903 | 1003212 | QRCODE
2022-01-18 19:36:10.418868 | 1003212 | QRCODE
2022-01-18 19:36:10.441220 | 1003212 | QRCODE
2022-01-18 19:36:10.467487 | 1003212 | QRCODE
2022-01-18 19:36:10.491222 | 1003212 | QRCODE
2022-01-18 19:36:10.515083 | 1003212 | QRCODE
2022-01-18 19:36:10.540116 | 1003212 | QRCODE
2022-01-18 19:36:10.565472 | 1003212 | QRCODE
2022-01-18 19:36:10.590443 | 1003212 | QRCODE
2022-01-18 19:36:10.614461 | 1003212 | QRCODE
2022-01-18 19:36:10.636793 | 1003212 | QRCODE
2022-01-18 19:36:10.660072 | 1003212 | QRCODE
2022-01-18 19:36:10.684499 | 1003212 | QRCODE
2022-01-18 19:36:10.707917 | 1003212 | QRCODE
2022-01-18 19:36:10.730875 | 1003212 | QRCODE
2022-01-18 19:36:10.755444 | 1003212 | QRCODE
2022-01-18 19:36:10.781072 | 1003212 | QRCODE
2022-01-18 19:36:10.807139 | 1003212 | QRCODE
2022-01-18 19:36:10.831537 | 1003212 | QRCODE
2022-01-18 19:36:10.856061 | 1003212 | QRCODE
2022-01-18 19:36:10.879412 | 1003212 | QRCODE
2022-01-18 19:36:10.907208 | 1003212 | QRCODE
2022-01-18 19:36:10.932153 | 1003212 | QRCODE
2022-01-18 19:36:10.957263 | 1003212 | QRCODE
2022-01-18 19:36:10.979708 | 1003212 | QRCODE
2022-01-18 19:36:11.004669 | 1003212 | QRCODE
2022-01-18 19:36:11.027284 | 1003212 | QRCODE
2022-01-18 19:36:11.053558 | 1003212 | QRCODE
2022-01-18 19:36:11.076448 | 1003212 | QRCODE
2022-01-18 19:36:11.103125 | 1003212 | QRCODE
2022-01-18 19:36:11.127427 | 1003212 | QRCODE
2022-01-18 19:36:11.152790 | 1003212 | QRCODE
2022-01-18 19:36:11.177483 | 1003212 | QRCODE
2022-01-18 19:36:11.201816 | 1003212 | QRCODE
2022-01-18 19:36:11.226943 | 1003212 | QRCODE
2022-01-18 19:36:11.252328 | 1003212 | QRCODE
2022-01-18 19:36:11.278298 | 1003212 | QRCODE
2022-01-18 19:36:11.304489 | 1003212 | QRCODE
2022-01-18 19:36:11.328390 | 1003212 | QRCODE
2022-01-18 19:36:11.353494 | 1003212 | QRCODE
2022-01-18 19:36:11.378955 | 1003212 | QRCODE
2022-01-18 19:36:11.404609 | 1003212 | QRCODE
2022-01-18 19:36:11.428431 | 1003212 | QRCODE
2022-01-18 19:36:11.451391 | 1003212 | QRCODE
2022-01-18 19:36:11.474968 | 1003212 | QRCODE
2022-01-18 19:36:11.498428 | 1003212 | QRCODE
2022-01-18 19:36:11.521937 | 1003212 | QRCODE
2022-01-18 19:36:11.545928 | 1003212 | QRCODE
2022-01-18 19:36:11.572425 | 1003212 | QRCODE
2022-01-18 19:36:11.594347 | 1003212 | QRCODE
2022-01-18 19:36:11.622728 | 1003212 | QRCODE
2022-01-18 19:36:11.648034 | 1003212 | QRCODE
2022-01-18 19:36:11.671617 | 1003212 | QRCODE
2022-01-18 19:36:11.695188 | 1003212 | QRCODE
2022-01-18 19:36:11.720437 | 1003212 | QRCODE
2022-01-18 19:36:11.746586 | 1003212 | QRCODE
2022-01-18 19:36:11.771024 | 1003212 | QRCODE
2022-01-18 19:36:11.795637 | 1003212 | QRCODE
2022-01-18 19:36:11.822281 | 1003212 | QRCODE
2022-01-18 19:36:11.845846 | 1003212 | QRCODE
2022-01-18 19:36:11.872049 | 1003212 | QRCODE
2022-01-18 19:36:11.894659 | 1003212 | QRCODE
2022-01-18 19:36:11.919739 | 1003212 | QRCODE
2022-01-18 19:36:11.942663 | 1003212 | QRCODE

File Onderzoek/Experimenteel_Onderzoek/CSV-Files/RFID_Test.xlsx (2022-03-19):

32D0D8B6
32D0D8B6
32D0D8B6
32D0D8B6
32D0D8B6
32D0D8B6
32D0D8B6
32D0D8B6
32D0D8B6
32D0D8B6
32D0D8B6
32D0D8B6
32D0D8B6
32D0D8B6
32D0D8B6
32D0D8B6
32D0D8B6
32D0D8B6
32D0D8B6
32D0D8B6
32D0D8B6
32D0D8B6
32D0D8B6
32D0D8B6
32D0D8B6
32D0D8B6
32D0D8B6
32D0D8B6
32D0D8B6
32D0D8B6
32D0D8B6
32D0D8B6
32D0D8B6
32D0D8B6
32D0D8B6
32D0D8B6
32D0D8B6
32D0D8B6
32D0D8B6
32D0D8B6
32D0D8B6
32D0D8B6
32D0D8B6
Authentication error
32D0D8B6
32D0D8B6
32D0D8B6
32D0D8B6
32D0D8B6
32D0D8B6
32D0D8B6
32D0D8B6
32D0D8B6
32D0D8B6
32D0D8B6
32D0D8B6
32D0D8B6
32D0D8B6
32D0D8B6
32D0D8B6
32D0D8B6
32D0D8B6
32D0D8B6
32D0D8B6
32D0D8B6
32D0D8B6
32D0D8B6
32D0D8B6
32D0D8B6
32D0D8B6
32D0D8B6
32D0D8B6
32D0D8B6
32D0D8B6
32D0D8B6
32D0D8B6
32D0D8B6
32D0D8B6
32D0D8B6
32D0D8B6
32D0D8B6
32D0D8B6
32D0D8B6
32D0D8B6
32D0D8B6
32D0D8B6
32D0D8B6
32D0D8B6
32D0D8B6
32D0D8B6
32D0D8B6
32D0D8B6
32D0D8B6
32D0D8B6
32D0D8B6
32D0D8B6
32D0D8B6
32D0D8B6
32D0D8B6
32D0D8B6

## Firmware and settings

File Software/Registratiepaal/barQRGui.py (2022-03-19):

#Copyright 2022 - Project Group: 'Help de RDM werkplaatsen met een registratiesysteem'
#Working 04-02-2022 with Python 3.9.2 on Raspberry Pi 3b

from guizero import App, Text, Window, Picture, Box
from pynput.keyboard import Listener, Key
import threading
from gpiozero import Buzzer
from time import sleep
import requests as rq

# ===============================================

#    Workshops:
#    0 = Aqualab
#    1 = Elektrolab
#    2 = Energielab
#    3 = Houtwerkplaats
#    4 = Lijmlab
#    5 = Materialenlab
#    6 = Metaalwerkplaats
#    7 = Mobiliteitslab
#    8 = Protolab

#Change to a number from workshoplist above:
workshopNumber = 6

# ===============================================

workshopList = ["Aqualab", "Elektrolab", "Energielab", "Houtwerkplaats", "Lijmlab", "Materialenlab", "Metaalwerkplaats", "Mobiliteitslab", "Protolab"]
articleList = ["de", "het"]

workshop = workshopList [workshopNumber]

articleGUIText = ""
if (workshop == workshopList [3] or workshop == workshopList [6]):
    articleGUIText = articleList [0]
else: 
    articleGUIText = articleList [1] 

# ===============================================

app = App (title="RegistratiePaalGUI", width=800, height=480)
app.set_full_screen ()
text = Text (app, "\n")
pictureBox = Box (app)
hrlogo = Picture (pictureBox, image="LogoRDM.png", width=750, height=150)
Text (app, "\nWelkom bij {} {}\n\nLeg een van deze codes op het plankje:\n- QR-Code uit HR-app\n- Barcode op HR-pas  ".format (articleGUIText, workshop), size=30)

windowSuccess = Window (app, title="Success", visible=False, width=800, height=480)
windowSuccess.set_full_screen ()
Text (windowSuccess, "\n")
Picture (windowSuccess, image="vinkje.png", width=400, height=400)

windowFailed = Window (app, title="Failed", visible=False, width=800, height=480)
windowFailed.set_full_screen ()
Text (windowFailed, "\n")
Picture (windowFailed, image="kruis.png", width=400, height=400)

windowConnError = Window (app, title="Connection Error", visible=False, width=800, height=480)
windowConnError.set_full_screen ()
Text (windowConnError, "\n\nEr kan geen connectie worden gemaakt\nmet het internet of de API.\n\nControleer de internetaansluiting en\nraadpleeg anders een medewerker.\n\nProbeer het later opnieuw.", size=30)

windowAPI400 = Window (app, title="API 400 Status Code", visible=False, width=800, height=480)
windowAPI400.set_full_screen ()
Text (windowAPI400, "\n\nHTTP 400: Bad Request\n\nProbeer het later opnieuw.", size=30)

windowAPI401 = Window (app, title="API 401 Status Code", visible=False, width=800, height=480)
windowAPI401.set_full_screen ()
Text (windowAPI401, "\n\nHTTP 401: Student niet geregistreerd\n\nNeem contact op met de administratie.", size=30)

windowAPI404 = Window (app, title="API 404 Status Code", visible=False, width=800, height=480)
windowAPI404.set_full_screen ()
Text (windowAPI404, "\n\nHTTP 404\n\nDe opgevraagde pagina kan niet\nworden geladen.\n\nProbeer het later opnieuw.", size=30)

windowAPI500 = Window (app, title="API 500 Status Code", visible=False, width=800, height=480)
windowAPI500.set_full_screen ()
Text (windowAPI500, "\n\nHTTP 500: Internal Server Error\n\nProbeer het later opnieuw.", size=30)

listen = True
def open_window (currentWindow, windowType):
    global listen
    listen = False
    currentWindow.show (wait=True)
    
    if (windowType == "failed"):
        threadBuzzInvalid ()
    elif (windowType == "success"):
        threadBuzzValid ()
        
    currentWindow.after (2000, lambda: close_window (currentWindow))

def open_window_error (currentWindow):
    global listen
    listen = False
    currentWindow.show (wait=True)
    threadBuzzInvalid ()
    currentWindow.after (10000, lambda: close_window (currentWindow))
    
def close_window (currentWindow):
    global listen
    currentWindow.hide ()
    listen = True

# ===============================================

buzzer = Buzzer (12) #GPIO Pin 12 Raspberry Pi

def buzzValid ():
    buzzer.value = 1
    sleep (0.6)
    buzzer.value = 0

timeX = 0.2
def buzzInvalid ():
    buzzer.value = 1
    sleep (timeX)
    buzzer.value = 0
    sleep (timeX)
    buzzer.value = 1
    sleep (timeX)
    buzzer.value = 0
    sleep (timeX)
    buzzer.value = 1
    sleep (timeX)
    buzzer.value = 0

def threadBuzzValid ():
    buzzerThread = threading.Thread (target = buzzValid ())
    buzzerThread.start ()
    
def threadBuzzInvalid ():
    buzzerThread = threading.Thread (target = buzzInvalid ())
    buzzerThread.start ()

# ===============================================

studentNumList = list ()

def listToString (inputList): 
    returnString = "" 
    return (returnString.join (inputList))

# ===============================================
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

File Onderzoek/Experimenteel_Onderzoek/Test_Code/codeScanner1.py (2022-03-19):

# import the necessary packages
from imutils.video import VideoStream
from pyzbar import pyzbar
import argparse
import datetime
import imutils
from time import sleep, time
import cv2
from gpiozero import Buzzer, LED, PWMOutputDevice
from threading import Thread

# construct the argument parser and parse the arguments
ap = argparse.ArgumentParser ()
ap.add_argument ("-o", "--output", type=str, default="barcodes.csv",
    help="path to output CSV file containing barcodes")
args = vars (ap.parse_args())

# initialize the video stream and allow the camera sensor to warm up
print ("[INFO] starting video stream...")
# vs = VideoStream(src=0).start()
vs = VideoStream (usePiCamera=True).start ()
sleep(2.0)

# open the output CSV file for writing and initialize the set of
# barcodes found thus far
csv = open (args["output"], "w")
found = set ()

#buzzer and LED shiz
buzzer = Buzzer (12)
led = LED (14)

timeOn = 0.5
timeOff = 1

def buzzAndLed():
    buzzer.toggle ()
    led.toggle ()
    sleep (timeOn)
    buzzer.toggle ()
    led.toggle ()

# loop over the frames from the video stream
scanCount = 0
startTime = time ()
deltaTime = 0
while True:
    # grab the frame from the threaded video stream and resize it to
    # have a maximum width of 400 pixels
    frame = vs.read()
    frame = imutils.resize(frame, width=400)
    
    # find the barcodes in the frame and decode each of the barcodes
    code = pyzbar.decode(frame) #barcodes = list
    
    if code: #barcode is true if list has an item
        thread1 = Thread(target = buzzAndLed)
        thread1.start ()
        
        codeData = code[0].data.decode ("utf-8")
        codeType = code[0].type
        
        # print text in shell
        text = "{} ({})".format (codeData, codeType)
        print (text)
        scanCount += 1
        if (scanCount >= 101):
            deltaTime = time () - startTime
            break
        print ("Scan Count:", scanCount)
        
        # if the barcode text is currently not in our CSV file, write
        # the timestamp + barcode to disk and update the set
        if codeData or codeType not in found:
            csv.write("{}, {}, {}\n".format (datetime.datetime.now (),
                codeData,
                codeType))
            csv.flush ()
            found.add (codeData)
            
        #sleep (timeOff)    

    # show the output frame
    cv2.imshow ("Code Scanner", frame)
    key = cv2.waitKey (1) & 0xFF
 
    # if the `q` key was pressed, break from the loop
    if key == ord ("q"):
        break
    
# close the output CSV file do a bit of cleanup
print ("Delta Time:", deltaTime)
print ("[INFO] cleaning up...")
csv.close ()
cv2.destroyAllWindows ()
vs.stop ()
